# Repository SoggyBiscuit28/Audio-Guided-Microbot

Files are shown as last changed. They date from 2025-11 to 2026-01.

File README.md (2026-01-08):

Review Assignment Due Date (https://classroom.github.com/a/Ei5Ot7FV)

# Audio-Guided Microbot

### Team Biscuit

A voice-controlled microbot using ESP32-S3 with on-device machine learning for real-time audio command recognition.

---

## Overview

This project implements a microbot that responds to voice commands (Forward, Backward, Left, Right) using TensorFlow Lite Micro for on-device inference. The system includes BLE communication for manual override and a Python GUI for monitoring.

## Repository Structure

| Folder | Description |
|---|---|
| [`Code/`](./Code/) | ESP32-S3 firmware, GUI application, and ML model training notebooks |
| [`Demos/`](./Demos/) | Demo video and images |
| [`Presentation/`](./Presentation/) | Final evaluation presentation (PDF) |
| [`Report/`](./Report/) | Project report |

## Quick Links

- 📹 [Demo Video](https://drive.google.com/file/d/1aCh8zQsNOZ-Cvipodxt4e_dWg6QOUhP8/view?usp=drivesdk)
- 📁 [Code Documentation](./Code/README.md)

## Tech Stack

- **Hardware:** ESP32-S3, I2S MEMS Microphone, DRV8833 Motor Driver
- **Firmware:** PlatformIO, Arduino Framework, TensorFlow Lite Micro
- **GUI:** Python, PySide6, BLE Communication
- **ML:** TensorFlow/Keras, MFCC Feature Extraction

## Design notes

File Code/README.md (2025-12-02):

# Audio-Guided Microbot - Code Documentation

This folder contains all the source code for the Audio-Guided Microbot project. The system enables voice command control of a microbot using an ESP32-S3 with on-device machine learning for audio classification.

## Table of Contents

- [Overview](#overview)
- [Folder Structure](#folder-structure)
- [Components](#components)
  - [Firmware](#firmware)
  - [Communication Classification](#communication-classification)
  - [GUI](#gui)
  - [Model Training](#model-training)
- [Hardware Requirements](#hardware-requirements)
- [Getting Started](#getting-started)

---

## Overview

The Audio-Guided Microbot is an embedded system that:
- Captures audio input via I2S MEMS microphone
- Processes audio using on-device neural network inference (TensorFlow Lite Micro)
- Classifies voice commands (Forward, Backward, Left, Right)
- Controls motors based on recognized commands
- Communicates with a companion GUI via BLE for manual override and monitoring
- Includes obstacle detection using ultrasonic sensors

---

## Folder Structure

```
Code/
├── README.md                           # This file
├── Communication_Classification/       # ESP32 code for BLE and LoRa testing/classification
│   ├── BLE/
│   │   ├── Client.ino                  # BLE client for throughput testing
│   │   └── Server.ino                  # BLE server for throughput testing
│   └── LoRa/
│       ├── receiver.ino                # LoRa receiver with RSSI/SNR logging
│       └── Transmitter.ino             # LoRa transmitter for range testing
├── firmware/                           # Main ESP32-S3 firmware (PlatformIO project)
│   ├── platformio.ini                  # PlatformIO configuration
│   ├── src/
│   │   ├── main.cpp                    # Main application entry point
│   │   ├── config.h                    # Hardware pin configurations
│   │   ├── CommandDetector.cpp/.h      # Audio gating and command detection
│   │   ├── CommandProcessor.cpp/.h     # Command execution logic
│   │   ├── ble_commands.h              # BLE communication handlers
│   │   └── neopixel_motorpin.h         # Motor and NeoPixel pin definitions
│   └── lib/
│       ├── audio_input/                # I2S microphone sampling library
│       │   ├── I2SMicSampler.cpp/.h    # I2S MEMS microphone driver
│       │   ├── I2SSampler.cpp/.h       # Base sampler class
│       │   └── RingBuffer.h            # Circular buffer for audio samples
│       ├── audio_processor/            # Audio feature extraction
│       │   └── src/
│       │       ├── AudioProcessor.cpp/.h   # MFCC feature extraction
│       │       ├── HammingWindow.cpp/.h    # Hamming window function
│       │       └── kissfft/                # FFT library
│       ├── neural_network/             # TensorFlow Lite Micro inference
│       │   └── src/
│       │       ├── model.cc/.h         # Trained model weights
│       │       └── NeuralNetwork.cpp/.h    # Inference wrapper
│       └── tfmicro/                    # TensorFlow Lite Micro library
│           ├── tensorflow/             # TF Lite Micro core
│           └── third_party/            # Dependencies (flatbuffers, gemmlowp, ruy)
├── GUI/                                # Graphical User Interface
│   ├── ESP32/
│   │   └── Client.ino                  # ESP32 BLE client (connects laptop to microbot)
│   └── python_GUI/
│       ├── ble_gui.py           # PySide6 GUI for robot control and monitoring
│       └── requirements.txt            # Python dependencies for GUI
└── model/                              # Machine Learning model training
    ├── Generate Training Data Command Recognition.ipynb    # Data generation notebook
    ├── Train Model-All Words.ipynb                         # Model training notebook
    ├── Convert Trained Model To TFLite.ipynb               # TFLite conversion notebook
    └── requirements.txt                                    # Python dependencies
```

---

## Components

### Firmware

**Location:** `firmware/`

The main ESP32-S3 firmware that runs on the microbot. Built with PlatformIO using the Arduino framework.

**Key Features:**
- **Audio Input:** Captures audio via I2S MEMS microphone at 16kHz
- **Audio Gating:** Energy-based voice activity detection to filter noise
- **Neural Network Inference:** TensorFlow Lite Micro for on-device command recognition
- **Motor Control:** PWM-based motor control with joystick override support
- **BLE Communication:** Receives commands and sends status updates
- **Obstacle Detection:** Ultrasonic sensor integration for collision avoidance
- **Voltage Monitoring:** ADC-based battery voltage monitoring

**Supported Commands:**
| Code | Command | Action |
|---|---|---|
| 0 | Toggle Override | Enable/disable voice command mode |
| 1 | Forward | Move forward for 5 seconds |
| 2 | Backward | Move backward for 5 seconds |
| 3 | Left | Turn left for 5 seconds |
| 4 | Right | Turn right for 5 seconds |
| 6 | Controller Mode | Toggle joystick override mode |

**Pin Configuration (ESP32-S3):**
| Pin | Function |
|-----|---|
| GPIO18 | I2S Mic Serial Data |
| GPIO19 | I2S Mic Left/Right Clock |
| GPIO20 | I2S Mic Serial Clock |
| GPIO7 | ADC Voltage Sensor |
| GPIO4 | Ultrasonic Trigger |
| GPIO5 | Ultrasonic Echo |

---

### Communication Classification

**Location:** `Communication_Classification/`

Contains test code for evaluating BLE and LoRa communication protocols for the microbot.

#### BLE Testing
- **Server.ino:** Creates a BLE server that measures throughput by receiving data packets
- **Client.ino:** BLE client that sends test payloads and measures RSSI

#### LoRa Testing
- **Transmitter.ino:** Transmits packets at configurable intervals with SF12/BW125kHz
- **receiver.ino:** Receives packets and logs RSSI, SNR, and packet statistics

**LoRa Configuration:**
| Parameter | Value |
|---|---|
| Frequency | 433 MHz |
| Spreading Factor | 12 |
| Bandwidth | 125 kHz |
| Coding Rate | 4/5 |
| TX Power | 20 dBm |

---

### GUI

**Location:** `GUI/`

A Python-based graphical user interface for controlling and monitoring the microbot.

#### ESP32 Client (`ESP32/Client.ino`)
- Runs on a separate ESP32 connected to the laptop via USB
- Acts as a BLE bridge between the Python GUI and the ESP32-S3 microbot
- Forwards serial commands as BLE writes
- Receives BLE notifications and prints them to serial

#### Python GUI (`python_GUI/ble_gui.py`)
A modern PySide6 application with:

**Features:**
- Serial port selection with auto-baud detection
- Real-time communication console
- Robot movement controls (Forward, Backward, Left, Right)
- Keyboard arrow key shortcuts
- Xbox controller/joystick support for analog control
- Battery level monitoring with voltage display
- Current and voltage line graphs
- Speed indicator
- Obstacle detection status
- Motion state display
- Override mode toggles

**Requirements:**
```
PySide6
pyserial
pygame (optional, for joystick support)
```

---

### Model Training

**Location:** `model/`

Jupyter notebooks for training the voice command recognition model.

#### Notebooks:
1. **Generate Training Data Command Recognition.ipynb**
   - Generates synthetic training data for voice commands
   - Creates spectrograms and audio features

2. **Train Model-All Words.ipynb**
   - Trains a CNN model for command classification
   - Supports 4 command classes: Forward, Backward, Left, Right

3. **Convert Trained Model To TFLite.ipynb**
   - Converts the trained Keras model to TensorFlow Lite format
   - Quantizes the model for embedded deployment
   - Generates C header file for embedding in firmware

**Model Architecture:**
- Input: MFCC features from audio spectrograms
- Output: 4-class softmax (Forward, Backward, Left, Right)
- Optimized for ESP32-S3 with ~300KB tensor arena

---

## Hardware Requirements

- **ESP32-S3 DevKitC-1** (main microbot controller)
- **ESP32** (BLE bridge for laptop communication)
- **I2S MEMS Microphone** (e.g., INMP441)
- **DRV8833 Motor Driver** or similar H-bridge
- **DC Motors** (2x for differential drive)
- **HC-SR04 Ultrasonic Sensor**
- **LiPo Battery** with voltage divider for monitoring
- **NeoPixel LED** (optional, for status indication)

---

## Getting Started

### Firmware Setup

1. Install [PlatformIO](https://platformio.org/) in VS Code
2. Open the `firmware/` folder in PlatformIO
3. Connect ESP32-S3 via USB
4. Update `upload_port` and `monitor_port` in `platformio.ini` for your OS:
   ```ini
   ; Windows example
   upload_port = COM3
   monitor_port = COM3
   ```
5. Build and upload:
   ```bash
   pio run --target upload
   ```

### GUI Setup

1. Upload `GUI/ESP32/Client.ino` to a separate ESP32 using Arduino IDE
2. Install Python dependencies:
   ```bash
   pip install -r GUI/python_GUI/requirements.txt
   ```
3. Connect the ESP32 client to your laptop via USB
4. Run the GUI:
   ```bash
   python GUI/python_GUI/nble_gui.py
   ```

### Model Training

1. Install Jupyter and dependencies:
   ```bash
   pip install -r model/requirements.txt
   ```
2. Run notebooks in order:
   - Generate Training Data → Train Model → Convert to TFLite
3. Copy the generated model header to `firmware/lib/neural_network/src/model.cc`

---

## Communication Protocol

The GUI communicates with the microbot via BLE using simple text commands:

| Command | Description |
|---|---|
| `0` | Toggle voice command mode |
| `1` | Move forward |
| `2` | Move backward |
| `3` | Turn left |
| `4` | Turn right |
| `6` | Toggle joystick controller mode |
| `J x.xxx y.yyy` | Joystick vector (x, y in range -1.0 to 1.0) |

**BLE Service UUID:** `4fafc201-1fb5-459e-8fcc-c5c9c331914b`  
**BLE Characteristic UUID:** `beb5483e-36e1-4688-b7f5-ea07361b26a8`

---

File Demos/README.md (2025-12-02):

# Demo Videos

This folder contains demonstration videos of the Audio-Guided Microbot project.

## Project Demo

📹 **[Watch the Demo Video](https://drive.google.com/file/d/1aCh8zQsNOZ-Cvipodxt4e_dWg6QOUhP8/view?usp=drivesdk)**

The demo showcases:
- Voice command recognition (Forward, Backward, Left, Right)
- Real-time motor control based on audio classification
- BLE communication with the companion GUI
- Obstacle detection and avoidance
- Manual override using the Python GUI

---

## Features Demonstrated

| Feature | Description |
|---|---|
| Voice Commands | ESP32-S3 recognizes spoken commands using on-device ML |
| Motor Control | Differential drive responds to classified commands |
| BLE Communication | Real-time status updates and manual control |
| Obstacle Detection | Ultrasonic sensor prevents collisions |
| GUI Control | Python application for monitoring and override |
---

### Link
https://drive.google.com/file/d/1aCh8zQsNOZ-Cvipodxt4e_dWg6QOUhP8/view?usp=drivesdk

---

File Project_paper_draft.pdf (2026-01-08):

# Energy-Efficient Keyword Spotting for Autonomous Microbots using Gated CNN on Edge

Ayush
Dept. of Computer Science Engineering IIIT Hyderabad
Hyderabad, India

Pranav
Dept. of Computer Science Engineering IIIT Hyderabad
Hyderabad, India

Yashav
Dept. of Computer Science Engineering IIIT Hyderabad
Hyderabad, India

Raza
Dept. of Computer Science Engineering IIIT Hyderabad
Hyderabad, India

Abstract—Voice-controlled micro-robots typically rely on cloud-based processing, which introduces latency and privacy concerns. Edge-based solutions are constrained by limited battery life and computational resources. This letter presents an energy-efficient Keyword Spotting (KWS) system implemented on an ESP32-S3 microcontroller for a differential drive microbot. We propose a multi-stage gating mechanism combining Signal-to-Noise Ratio (SNR), Root Mean Square (RMS) energy, and Zero-Crossing Rate (ZCR) to filter non-speech audio before invoking a lightweight Convolutional Neural Network (CNN). The system achieves a command recognition latency of approximately 102 ms and extends battery life by preventing unnecessary model inference. Experimental results demonstrate robust offline control with high accuracy for four directional commands.
Index Terms—Keyword Spotting, Edge AI, Embedded Systems, Micro-robotics, Convolutional Neural Networks.
I. INTRODUCTION

Voice User Interfaces (VUI) have become a dominant modality for human-machine interaction, driven by the ubiquity of smart speakers and virtual assistants. At the core of these systems lies Keyword Spotting (KWS), a classification task designed to detect a predefined set of words or phrases within a continuous stream of audio. Unlike Large Vocabulary Continuous Speech Recognition (LVCSR) which transcribes full sentences, KWS focuses on identifying specific triggers, making it the critical first step in command-and-control applications.
Deploying robust KWS on the “edge”—specifically on microcontrollers (MCUs)—presents a distinct set of challenges compared to server-grade implementations. Edge devices, such as the ESP32-S3 used in this work, operate under severe resource constraints. They typically possess limited Static RAM (SRAM) for storing intermediate tensors and Flash memory for model weights. Furthermore, they lack the powerful GPUs found in cloud servers, relying instead on low-power CPUs or specialized vector instructions. Achieving high accuracy with low latency while fitting the model into these constraints requires careful architectural design and optimization, such as quantization.

A critical bottleneck in battery-operated edge KWS is energy consumption. Deep learning models, particularly Convolutional Neural Networks (CNNs), involve millions of multiply-accumulate (MAC) operations per inference. In a typical environment, a robot spends the vast majority of its time in silence or background noise. An “always-on” system that runs a full CNN inference on every audio frame is inherently inefficient, draining the battery rapidly even when no commands are spoken.

To address this, Our edge KWS system leverages a “gating” mechanism or Voice Activity Detection (VAD) stage. This technique introduces a hierarchical processing pipeline. A lowcomplexity, low-power algorithm continuously monitors the audio signal for speech-like characteristics. Only when this gate detects potential speech does it wake the downstream neural network to perform the expensive classification. This cascaded approach offers dual benefits: it drastically reduces the average power consumption by keeping the MCU in a lower-power state during silence, and it reduces false positives by filtering out non-speech acoustic events before they reach the classifier.

In this letter, we present a complete hardware and software implementation of an offline, voice-controlled microbot. We focus on optimizing the trade-off between recognition accuracy and energy consumption through a robust gating strategy and a quantized neural network.

This work makes the following contributions:

1) A lightweight CNN architecture optimized for the ESP32-S3 to recognize four navigational commands (Forward, Backward, Left, Right).
2) A robust multi-metric gating algorithm using Signal-to-Noise Ratio (SNR), Root Mean Square (RMS) energy, and Zero-Crossing Rate (ZCR) to filter noise and silence, significantly reducing computational load.
3) A complete offline implementation demonstrating real-time control with <120 ms latency and safety features.

II. SYSTEM ARCHITECTURE

The system is built around the Espressif ESP32-S3 SoC, which features a dual-core Xtensa LX7 processor with vector instructions (AI acceleration) and BLE 5.0.

A. Hardware Setup

The robot employs a differential drive configuration with N20 motors and a DRV8833 driver. Audio is captured via an INMP441 MEMS microphone using the I2S interface. An HC-SR04 ultrasonic sensor provides obstacle avoidance safety. Power is supplied by 4xAA batteries, necessitating strict energy management.

B. Software Pipeline

The processing pipeline consists of five stages:

1) Audio Acquisition: Continuous buffering of 16kHz audio samples.
2) Gating (VAD): Fast rejection of non-speech frames.
3) Feature Extraction: Conversion of raw audio to spectrograms.
4) Inference: 8-bit quantized CNN execution.
5) Post-Processing: Confidence thresholding and command execution.

III. PROPOSED METHOD

A. Multi-Stage Gating Mechanism

To minimize power consumption, we implement a “Speech Gate” that analyzes the raw audio buffer before feature extraction. The gate computes three metrics on the raw PCM data: Root Mean Square (RMS) energy, Zero-Crossing Rate (ZCR), and Signal-to-Noise Ratio (SNR).
The system maintains a running estimate of the background noise level (Nest) and noise ZCR (Zest), updated during non-speech frames using a first-order low-pass filter with an adaptive coefficient α:

Nest[t] = (1 − α) · Nest[t − 1] + α · AvgAbs[t] (1)

where α is set to 0.05 for noise-like frames and 0.005 otherwise, ensuring the noise floor adapts quickly to environmental changes but remains stable during speech.
The gate transitions to an “open” state only if a set of strict conditions are met for kmin = 2 consecutive frames:

(SNR > TSNR ∨ RMS > TRMS) ∧ (ZCR < TZCR) (2)

where TSNR = 1.25, TRMS = 58.5, and TZCR = 0.28. A secondary “Strong” threshold set (TSNR High = 2.15, TRMS High = 106.5) allows for faster triggering on clear, loud commands. Once triggered, the gate remains open for a “hangover” period of 4 frames to capture the tail of the utterance.

B. Feature Extraction
Upon gate activation, the system processes a 1-second audio buffer (L = 16000 samples). We compute a spectrogram using a sliding Hamming window of size W = 320 (20 ms) with a step size of S = 160 (10 ms). For each window, a 512-point Fast Fourier Transform (FFT) is computed.
To reduce dimensionality, the magnitude squared of the FFT bins is pooled using average pooling with a kernel size of 6. The result is log-transformed to compress the dynamic range:

S[t, f] = log10

1
P

P

X⁻¹

i=0

|X[t, f · P + i]|

2 + ϵ

!
(3)

This yields a compact input tensor of shape (99, 43, 1), representing time, frequency, and channels respectively.

C. Lightweight CNN Architecture
We designed a compact CNN to fit within the ESP32-S3’s 384KB SRAM. The model takes a 99 × 43 × 1 spectrogram input and processes it through the following layers:
1) Conv2D: 4 filters, 3 × 3 kernel, ReLU activation, L2 regularization (0.001).
2) MaxPool2D: 2 × 2 pooling.
3) Conv2D: 4 filters, 3 × 3 kernel, ReLU activation, L2 regularization (0.001).
4) MaxPool2D: 2 × 2 pooling.
5) Flatten followed by Dropout (0.1).
6) Dense: 80 units, ReLU activation, L2 regularization (0.001), Dropout (0.1).
7) Output Dense: 5 units (Forward, Backward, Left, Right, Unknown), Softmax activation.
The model contains a total of 77,473 parameters. It is trained using the Adam optimizer and Categorical Cross-Entropy loss. Post-training, the model is converted to TensorFlow Lite for Microcontrollers (TFLite Micro) with full integer quantization (int8). This reduces the model size to approximately 81 kB, allowing it to reside entirely in the MCU’s internal flash and execute efficiently in RAM.
D. Post-Processing & Safety
Raw model probabilities are filtered to prevent false positives. A command Ci

is accepted only if its probability P(Ci) exceeds a class-specific threshold Ti (e.g., Tfwd = 0.70, Tlef t = 0.50) and the margin against the second-best class exceeds M = 0.15.

P(Ci) > Ti | ∧ | (P(Ci) − max j̸=i
P(Cj )) > M | (4)

A cooldown period of 1000 ms is enforced after a successful detection to prevent repeated triggering from echoes.

IV. EXPERIMENTAL RESULTS

A. Model Evaluation
The model was trained on a custom dataset of the four target commands plus a set of “unknown” words and background noise. The training process achieved a validation accuracy of 92.87%.

The confusion matrix (Table I) illustrates the model’s performance across all classes. The high diagonal values indicate robust classification, with minimal confusion between directional commands.

TABLE I
CONFUSION MATRIX (NORMALIZED)
True/Pred | Fwd | Back | Left | Right | Unk
Fwd | 0.94 | 0.01 | 0.02 | 0.01 | 0.02
Back | 0.01 | 0.93 | 0.01 | 0.02 | 0.03
Left | 0.02 | 0.01 | 0.91 | 0.01 | 0.05
Right | 0.01 | 0.02 | 0.01 | 0.92 | 0.04
Unk | 0.03 | 0.02 | 0.03 | 0.02 | 0.90
B. Latency and Performance
The end-to-end latency from the end of a spoken command to motor actuation was measured at approximately 102 ms. This falls well within the target of <120 ms for perceived real-time response.
C. Gating Efficiency
The gating mechanism successfully filters out background noise and silence. In a quiet environment, the gate remains closed >90% of the time, preventing the CPU from running the computationally intensive FFT and CNN inference. This significantly reduces the average current consumption.
D. Battery Life
On 4xAA batteries (approx. 2500mAh capacity), the robot achieves a runtime of:
- Idle (Listening): ∼3.5 hours
- Active (Moving): ∼2.25 hours (at 100% motor duty cycle)
E. Resource Usage
- Model Size: ∼81 kB
- Tensor Arena: 50 kB
- Inference Time: <100 ms
V. CONCLUSION
We presented a fully offline, voice-controlled microbot system. By combining a low-cost gating stage with a quantized CNN, we achieved robust command recognition on a resourceconstrained ESP32-S3. The system balances latency, accuracy, and power efficiency, making it suitable for low-power edge robotics applications. Future work will explore on-device learning to adapt to specific user voices.

REFERENCES

[1] Y. Zhang et al., “Hello Edge: Keyword Spotting on Microcontrollers,” arXiv preprint arXiv:1711.07128, 2017.
[2] P. Warden, “Speech Commands: A Dataset for Limited-Vocabulary Speech Recognition,” arXiv preprint arXiv:1804.03209, 2018.

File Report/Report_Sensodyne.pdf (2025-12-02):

# Audio Guided Microbot

### Documentation (Embedded Systems Workshop)

### Team Sensodyne (#17) — Ayush, Pranav, Yashav, Raza Under Prof. Abhishek Srivastava TA: Inesh Dheer

### December 2, 2025

### At a Glance (Our Project)

An autonomous microbot that listens for four simple voice commands (forward, back, left, right), moves safely, and can be taken over from a laptop with a joystick. All recognition happens on the bot (no internet). Bluetooth (BLE) is our main, encrypted link. LoRa is optional for long range. The bot stops if an obstacle is too close or if the link drops.

- Why this is useful: hands-free control, works offline and keeps audio private, easy supervision with a GUI.
- Core pieces: the mic (ears), a tiny on-device model (brain), motor driver + wheels (legs), ultrasonic sensor (safety), BLE (link), and a simple desktop GUI (eyes).

### Contents

1 Problem & Our Approach | 3
2 How the System Fits Together | 5
3 The Parts We Used (and why) | 5
4 The Brain: How We Understand the Voice | 6
5 Communication & Security (practical view) | 8
6 What the GUI shows (operator view) | 8
7 What happens on each command (simple behavior) | 9

8 What We Calibrated & Tested | 9
9 Results (short and clear) | 10
10 Challenges & What We Changed | 10
11 How to Run (In short) | 10
12 Implementation Details (how our code works, in simple words) | 10

### 1 Problem & Our Approach

### 1.1 Introduction

Small robots are great for demos, labs, and quick tasks—but most voice control systems depend on the cloud, which adds delay and privacy issues. Our goal was to make a tiny microbot that you can talk to in plain words (forward, back, left, right), that reacts quickly, stays safe around obstacles, and can be taken over instantly from a laptop—all while working fully offline.
The design favors:
- Simplicity for the operator: four clear voice commands, one clean GUI, and an instant Manual Override.
- Safety first: obstacle halts and link-loss stop; no surprises in crowded rooms.
- Privacy by default: on-device recognition—no audio leaves the bot.
- Practical hardware: ESP32-S3 with built-in BLE, a single digital mic, and a basic differential drive.

### 1.2 Problem Statement & Constraints

We want a voice-driven microbot that is fast, safe, and private, using inexpensive parts. It should understand four commands, move appropriately, and be supervise-able from a laptop. No cloud is allowed.

Functional requirements
- Recognize forward, back, left, right on-device and act on them.
- Halt forward motion automatically when an obstacle is detected at 6 cm.
- Provide a Manual Override via GUI to drive with joystick/keys at any time.
- Keep the operator informed with simple BLE messages: FORWARD, LEFT, OBSTACLE, IDLE, etc.
- Stop safely if the operator link is lost (short timeout, ∼400 ms).

Non-functional requirements
- Offline: no internet; audio never leaves the device.
- Low latency: decision in well under 150 ms (we achieve ∼102 ms).
- Small model: must fit in microcontroller memory (we use ∼81 kB).
- Low false triggers: practical guards for noisy rooms (energy/ZCR gate, short memory, per-command confidence, cooldown).
- Battery-friendly: run on 4×AA cells for a couple of hours (measured 2.25 3.5 h depending on duty).

Scope & assumptions (hardware/environment)
- Compute: ESP32-S3; on-board BLE; FreeRTOS tasks.
- Audio: single INMP441 digital mic; 16 kHz sampling; ∼1 s analysis window.
- Drive: DRV8833 + 2×N20 motors (differential); ultrasonic sensor (HC-SR04) facing forward.
- Typical spaces: classrooms, labs, corridors; normal indoor noise.
- Comms: BLE (primary, encrypted when paired); LoRa optional with app-level encryption when used.

### 1.3 Objectives & Success Criteria

- Command responsiveness: voice→action in ≤120 ms (met: ∼102 ms).
- Safety halt: forward motion stops at <6 cm and on link loss (met: periodic checks + timeout stop).
- Operator clarity: GUI mirrors state with simple words; Manual Override is instant.
- Robustness in noise: few/no unintended moves in typical indoor noise thanks to gating + thresholds + cooldown.
- Runtime on 4×AA: 2.25 −3.5 h depending on duty (measured, see §8.3).

### 1.4 Our Solution (high level)

- Listen & understand: a compact model on the ESP32-S3 recognizes forward/ back/left/right.
- Move safely: before and during forward motion, we check distance in front; halt at 6 cm.
- Stay connected: BLE is primary (encrypted by default when paired); optional LoRa adds range with an extra app-level lock (encryption) on messages.
- Be easy to control: a desktop GUI shows status and lets the operator drive instantly with a joystick.

### 2 How the System Fits Together

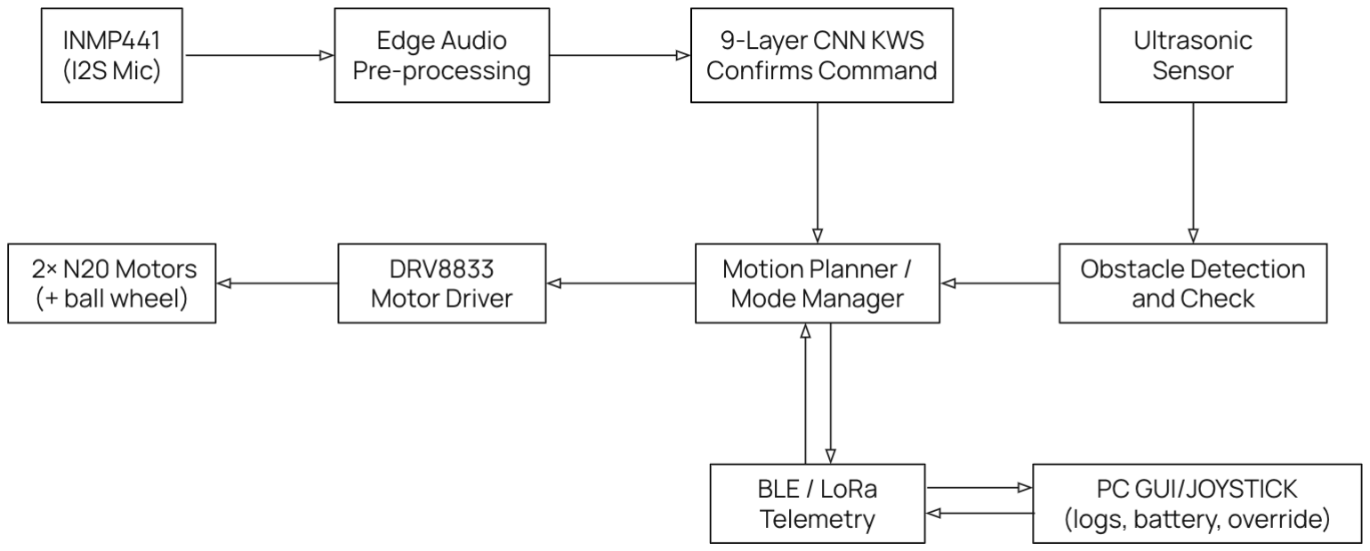
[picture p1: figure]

Figure 1: Mic (hear) → tiny model (decide) → safety check (stop if needed) → wheels (act). BLE links the bot to the GUI.

Simple flow Mic hears the word → we turn the sound into a small picture-like grid → the tiny model picks the best of four commands → a few “common-sense” checks avoid mistakes → motors run or stop → GUI shows what’s happening and can take over.

### 3 The Parts We Used (and why)

- ESP32-S3 board (brain): enough memory to run our tiny model on-device; built-in BLE keeps wiring simple.
- INMP441 microphone (ears): clean digital mic input.
- HC-SR04 ultrasonic (safety): halts forward motion within a set distance (default 6 cm).
- DRV8833 + 2×N20 motors (legs): sturdy differential drive; easy to control with four pins (IN1..IN4).
- Power: 4×AA cells with regulation; we measured runtime at different speeds (see §8.3).
- Shell & PCB: small 3D-printed cover and a simple PCB to avoid loose wires and reduce noise.

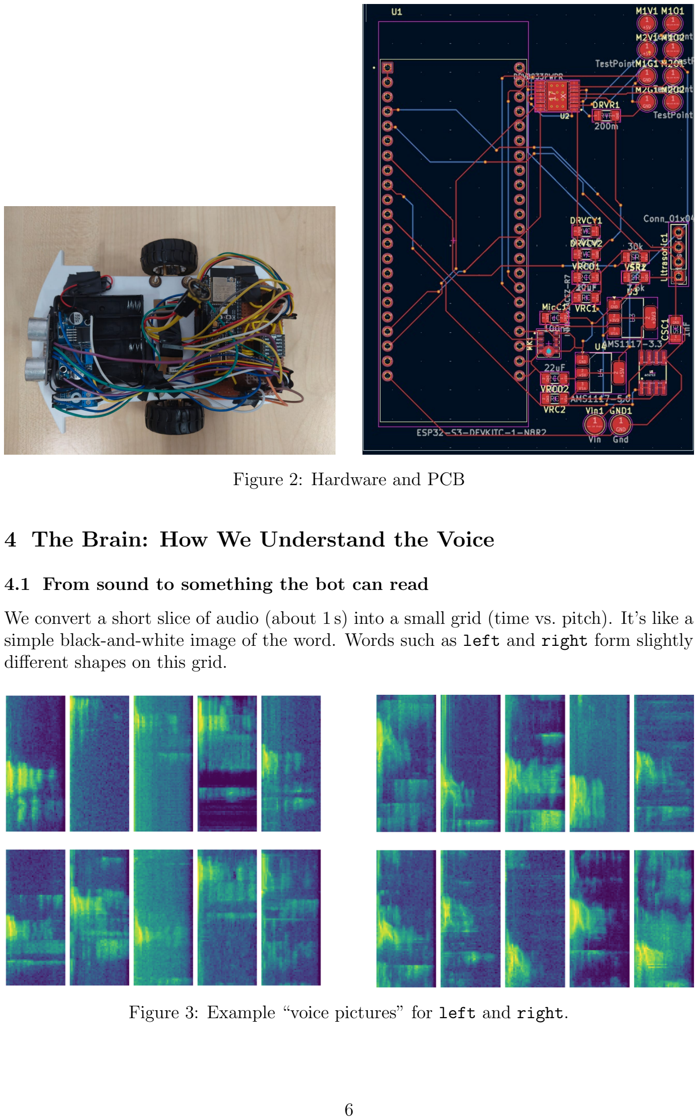
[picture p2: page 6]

Figure 2: Hardware and PCB

### 4 The Brain: How We Understand the Voice

### 4.1 From sound to something the bot can read

We convert a short slice of audio (about 1 s) into a small grid (time vs. pitch). It’s like a simple black-and-white image of the word. Words such as left and right form slightly different shapes on this grid.

Figure 3: Example “voice pictures” for left and right.

### 4.2 What the tiny model does

- A very small CNN looks for patterns in those grids.
- Size on device: ∼81 kB; decision time: ∼102 ms.
- Why this matters: quick reactions, fits in memory, fully offline (no privacy worries).

### 4.3 How we avoid mistakes in noisy rooms (practical guards)

We layer a few friendly checks around the model so the bot doesn’t move because of coughs or background talk.
1. Only listen when speech is present (a simple gate): we look at loudness, steadiness, and how often the signal crosses zero. If it looks like real speech, we “open the gate” and run the model; otherwise we skip it and treat it as silence.
2. Confidence per word: each command has its own “confidence to accept” and a “margin” over the second best. Clear words pass easily; unclear ones are ignored.
3. Short memory: we keep a tiny rolling window of the last few model outputs and accept only if the same command stays on top—this avoids one-frame spikes.
4. Cooldown: after acting on a word, we wait a bit before accepting the same word again—helps with echoes.

Quick reference (from firmware)

All of this is already coded; here are the friendly names and values your teammates will tweak most often.

Table 1: Speech gate (when to even run the model)

What it checks | Current setting

Needs to be louder than recent background (SNR) normal 1.25, “strong” 2.15
Minimum steady loudness (RMS) | normal 58.5, “strong” 106.5
Extra margin above average noise (abs delta) | 6.5
How busy the signal is (zero-crossing rate) | must be ≤ noise+margin; cap 0.28 (+0.08 margin)
Open gate after this many “hits” | 2 (keep open briefly for up to 600 ms)

Table 2: Accepting a command (per-word confidence)

Command | Min confidence Extra margin over 2nd
forward | 0.70 | 0.35
backward | 0.71 | 0.37
left | 0.50 | 0.18
right | 0.48 | 0.15
(unknown/silence) 0.50 | 0.20

Extra: when speech is very strong, the code can relax these slightly (to 0.45/0.15) so good words trigger faster. Cooldown between accepted commands: 1,000 ms. Debug status prints every 200 ms.

### 5 Communication & Security (practical view)

### 5.1 Bluetooth Low Energy (BLE) — our main link

BLE is the default. It’s quick, stable indoors, and already encrypted once paired (we use normal paired operation). We send short text updates like FORWARD, LEFT, OBSTACLE, IDLE so the GUI mirrors the bot’s state. If packets stop for a short time, the bot stops.

### 5.2 LoRa — optional long-range

When we need distance, we can switch to LoRa. Because LoRa itself isn’t end-to-end encrypted, we add a simple lock on the message (shared secret → encrypted payload) so packets stay private and tamper-evident.

### 6 What the GUI shows (operator view)

- One window to connect, see logs, battery and motion state.
- Manual Override button: instantly take control with keys or a joystick; the bot switches out of voice mode.
- Safety: if BLE packets stop arriving for a short time (∼400 ms), the bot auto-stops.

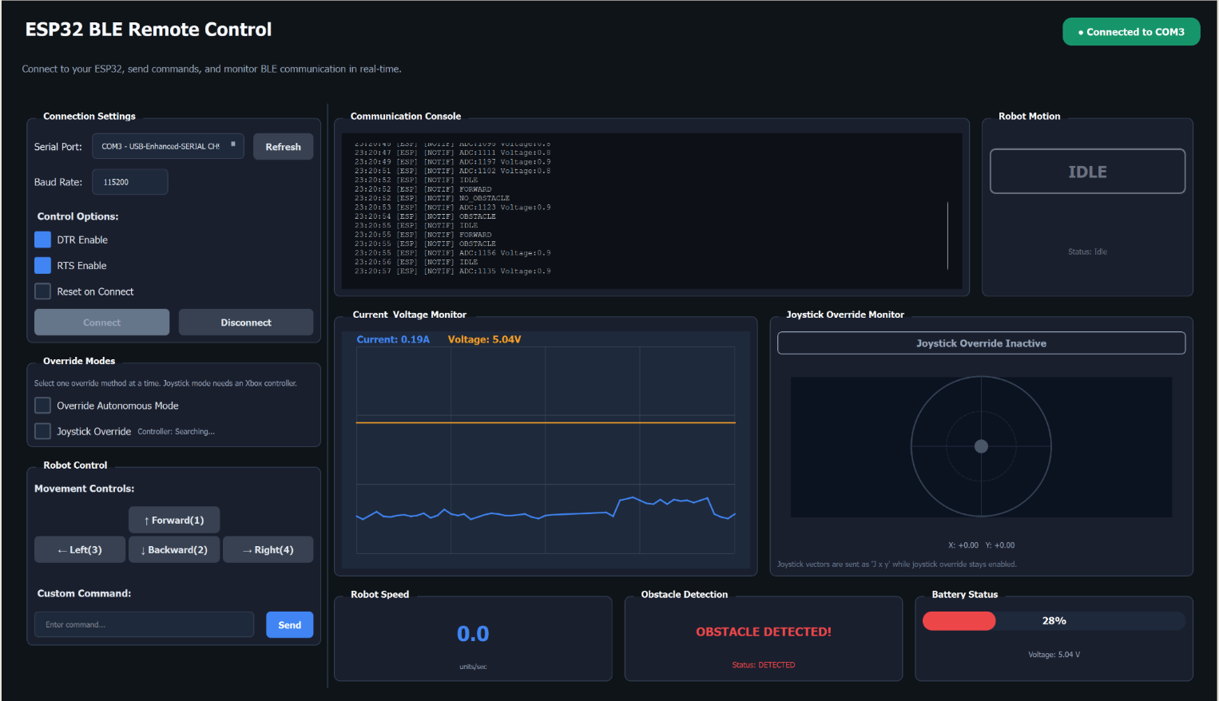
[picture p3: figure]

Figure 4: Remote GUI: status, logs, and joystick drive.

### 7 What happens on each command (simple behavior)

Below is how the bot moves after a command is accepted. We also send a short BLE message for the GUI.

Table 3: Command behavior (summarized from firmware)

Command Safety check | Motion pins (IN1..IN4) | Typical duration
forward | Check distance each step; stop < 6 cm 1:HIGH,2:LOW,3:LOW,4:HIGH | up to ∼9 s (rechecks every 200 ms)
backward | No front check needed | 1:LOW,2:HIGH,3:HIGH,4:LOW | ∼5 s
left | No front check needed | 1:HIGH,2:LOW,3:HIGH,4:LOW | ∼5 s (pivot)
right | No front check needed | 1:LOW,2:HIGH,3:LOW,4:HIGH | ∼5 s (pivot)

At the end of any move, we set all four pins LOW, send IDLE, and disable the motor
driver to save power.

Front distance sensor (forward only) We trigger the ultrasonic sensor, read the echo, and compute distance. If it’s valid and < 6 cm, we stop immediately; otherwise we continue but recheck frequently.

### 8 What We Calibrated & Tested

### 8.1 Audio & model

- Trim clips to keep speech; keep lengths consistent so the “voice picture” is stable.
- Tune confidence thresholds (per word) and cooldown until the bot feels both responsive and safe.
- In busy spaces, the speech gate + “short memory” window keep false triggers rare.

### 8.2 Motion & safety

- Map joystick values to left/right wheel speeds; add a small left/right correction so “straight” is truly straight.
- Verify the 6 cm stop distance with a ruler and adjust only if needed.

### 8.3 Battery life (4×AA (600mah each)

Table 4: Runtime vs. movement (measured)

Motor duty Avg current (A) Runtime (h) hh:mm

0% | 0.18 | ∼3.50 | ∼3:30
25% | 0.198 | ∼3.00 | ∼3:00
50% | 0.215 | ∼2.75 | ∼2:45
75% | 0.232 | ∼2.50 | ∼2:30
100% | 0.250 | ∼2.25 | ∼2:15

### 8.4 BLE and LoRa (field notes)

Indoors, BLE is strong across rooms and a couple of walls; very long hallways or lots of motion can weaken it. LoRa reaches far in open sight; when we use it, we keep our app-level lock (encryption) on messages.

### 9 Results (short and clear)

- On-device voice: ∼102 ms decision time; smooth in quiet rooms; usable in busy rooms thanks to the guards.
- Safety working: stops within 6 cm and also on link loss.
- Operator experience: joystick feels immediate; GUI is clear; manual override is instant.

### 10 Challenges & What We Changed

- Early plan used multiple mics to find direction—hardware wasn’t precise enough, so we pivoted to solid keyword control.
- A browser model worked online but not on the board; switching to a direct .tflite with a tiny runtime fixed it.
- Noise from wiring/breadboards caused false triggers; a PCB and the extra guards stabilized behavior.

### 11 How to Run (In short)

1. Flash the ESP32-S3 with the firmware that includes the tiny model file (.tflite).
2. Power the bot; pair over BLE from the GUI.
3. Choose Voice mode to use keywords, or tap Manual Override for joystick/keys.
4. Keep obstacles ≥ 6 cm in front when moving forward; if the link drops, the bot will stop on its own.

### 12 Implementation Details (how our code works, in simple words)

This section explains what actually runs on the board and how each piece talks to the next. We keep it practical and match the names you will see in code and logs.

### 12.1 Voice path: from mic to a decision

1. Keep the last ∼1 second of audio in memory We continuously sample the mic and store it in a ring buffer (AUDIO LENGTH=16000 samples). Why: when a word is spoken, we already have the recent audio to analyze.

2. Decide if this even sounds like speech (“open the gate”) Before running the tiny model, we check simple metrics over the last second: average loudness, steadiness (RMS), and how often the signal crosses zero (ZCR). If it looks like real speech (loud enough, steady enough, and not too “buzzy”), we open the gate; otherwise we skip this turn. Names in code: shouldRunInference(...) with thresholds like SNR 1.25 / 2.15, RMS 58.5 / 106.5, max ZCR 0.28 (+0.08 margin), min hits 2, release 600 ms. Why: saves time and avoids reacting to
coughs and background chatter.
3. Turn audio into a small “voice picture” With the gate open, we build a compact spectrogram (a time–pitch grid). Name in code: AudioProcessor::get spectrogram(...).
4. Run the tiny model on that picture The model returns 5 scores: forward,
backward, left, right, (unknown/silence). Name in code: m nn->predict();
m nn->getOutputBuffer().
5. Keep a short memory of recent outputs We store each new set of scores in a rolling window (COMMAND WINDOW rows). Internally we keep them as log values so combining them stays numerically stable. Name in code: cachePredictionRow(...) updates m scores[window][class].
6. Pick the best command, check confidence and margin We add up the windowed scores per class, compute a best class and a runner-up, then require: (a) Min confidence for that command, and (b) extra margin over the second place. Per-command thresholds in code:
- forward → 0.70 (min), 0.35 (margin)
- backward → 0.71, 0.37
- left → 0.50, 0.18
- right → 0.48, 0.15
- unknown/silence → 0.50, 0.20

When the speech looks very strong, the code can relax the generic thresholds slightly
(to ∼0.45/0.15) so good words trigger faster. Name in code: see kCommandProbabilityThresholds, kCommandProbabilityMargins and the accept command checks.
7. Cooldown so echoes don’t double-trigger After we act on a word, we wait 1000
ms before we accept the same word again. Name in code: kDetectionCooldownMs
= 1000.

Debugging while you test Every ∼200 ms we print a compact line showing gate status (loudness, ZCR, SNR), top command, probabilities, thresholds, and whether we accepted it. Name in code: kDebugLogIntervalMs = 200. This is the first place to look if the bot is too jumpy or too sleepy.

### 12.2 Command path: from a decision to motor motion

Once a command is accepted, we don’t move motors directly from the detector thread. Instead, we queue the command, and a separate task performs the action. Why: keeps the audio/model loop smooth and responsive.

1. Queue the command queueCommand(index, best score) pushes into a FreeR-TOS queue (xQueueSendToBack).
2. A dedicated task executes it commandQueueProcessorTask(...) waits on the queue and calls processCommand(index).
3. What each command does (summarized)
- forward Before moving, we ping the ultrasonic sensor and compute distance. If it’s valid and < 6 cm, we report OBSTACLE and do not move. Otherwise we enable the driver (DRV EEP = HIGH), set motor pins to forward (IN1=HIGH, IN2=LOW, IN3=LOW, IN4=HIGH) and keep rechecking distance roughly every 200 ms in a short loop. If at any step an obstacle comes within 6 cm, we stop immediately and report OBSTACLE.
- backward Enable driver and set reverse pins (IN1=LOW, IN2=HIGH, IN3=HIGH, IN4=LOW) for a brief, fixed duration.
- left/right Pivot in place by driving wheels in opposite directions. Left: (IN1=HIGH, IN2=LOW, IN3=HIGH, IN4=LOW). Right: (IN1=LOW, IN2=HIGH, IN3=LOW, IN4=HIGH).
4. Always finish safely After any command completes (or is interrupted by an obstacle), we: set IN1..IN4 = LOW, send IDLE over BLE, and disable the motor driver (DRV EEP = LOW) to save power.

BLE messages you’ll see in the GUI On each action we notify short, humanreadable strings: FORWARD, BACKWARD, LEFT, RIGHT, OBSTACLE, NO OBSTACLE, IDLE. These make it obvious what the bot is doing and why it stopped.

### 12.3 Safety logic (forward motion + link loss)

- Obstacle stop (forward only) The distance check runs before moving and during the forward run (periodic pings). If distance < 6 cm at any instant, we stop and show OBSTACLE.
- If the operator link drops The GUI sends frequent small updates. If those stop for a short window (∼400 ms), the bot falls back to IDLE/stop. Tip: if you’re testing without the GUI, keep voice mode enabled so the safety still holds.

### 12.4 Where to tune (friendly knobs)

- How eager the bot is to treat audio as speech: SNR/RMS/ZCR thresholds (“gate”). If it’s too jumpy, raise SNR/RMS or tighten ZCR. If it’s too sleepy, lower them slightly.
- How strict a word must be: per-command confidence and margin. If “right” is mis-heard, raise its threshold or margin a little.
- Repeat protection: cooldown (1000 ms). Increase for echoey rooms; decrease if you want rapid repeated turns.

### 12.5 What runs in parallel (timing picture)

- The detector loop samples audio, opens/closes the speech gate, builds the voice picture, runs the model, and decides on commands. It keeps the UI responsive by not touching motors directly.
- The command task takes accepted commands from the queue and handles motors + safety checks.
- The BLE/GUI loop shows state and allows instant Manual Override (it simply bypasses voice and drives the same motor pins).

### 12.6 If something feels off (quick troubleshooting)

- Bot triggers on noise: raise SNR/RMS gate; raise per-command confidence; check wiring/PCB ground.
- Bot misses clear words: slightly lower per-command threshold; reduce margin; ensure the mic opening is unobstructed.
- Forward keeps stopping: confirm ultrasonic wiring; measure if your desk is within 6 cm; try temporarily raising the stop distance to test.
- GUI shows no updates: re-pair BLE; ensure notifications are enabled; watch serial logs for IDLE/OBSTACLE.

### Appendix A — Parameters (from firmware)

- Audio slice length: AUDIO LENGTH = 16000 samples (≈ 1 s at 16 kHz).
- Window & step: WINDOW SIZE = 320 (≈ 20 ms), STEP SIZE = 160 (≈ 10 ms hop).
- Pooling: POOLING SIZE = 6 (compact “voice picture”).
- Gate thresholds: SNR 1.25/2.15, RMS 58.5/106.5, max ZCR 0.28 (+0.08), min hits 2, hangover hits 4, release 600 ms.
- Per-word acceptance: see table in §The Brain.
- Cooldown: 1000 ms; Debug print interval: 200 ms.
- BLE messages: "FORWARD", "BACKWARD", "LEFT", "RIGHT", "OBSTACLE", "NO OBSTACLE", "IDLE".
- Ultrasonic pins (example in code): TRIG GPIO 4, ECHO GPIO 5 (adjust if
your wiring differs).

### Appendix B — Figures added from the build

- figures/block-diagram.png (single architecture diagram)
- figures/hardware.jpg (top view of the bot)
- figures/pcb.jpg (assembled PCB)

- figures/spectrogram-left.png, figures/spectrogram-right.png
- figures/gui.png (GUI screenshot)

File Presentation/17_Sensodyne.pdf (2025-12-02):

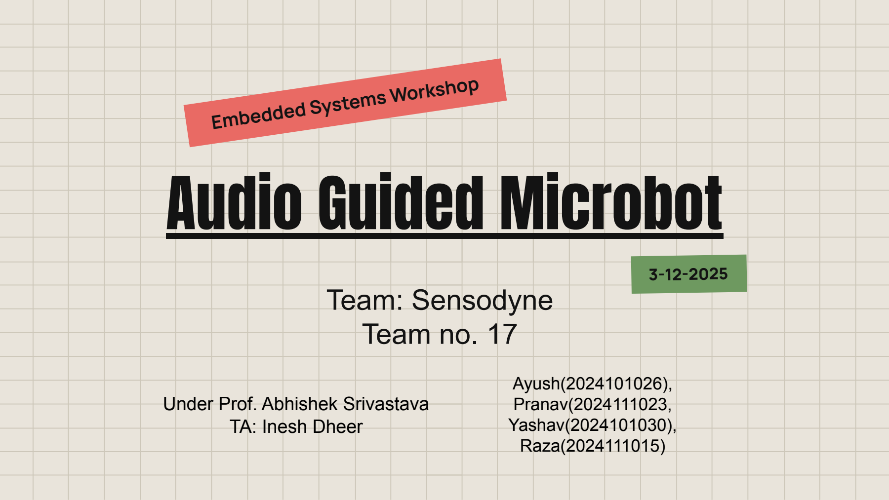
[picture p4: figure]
Audio Guided Microbot; Embedded Systems Workshop; Team: Sensodyne Team no. 17; Under Prof. Abhishek Srivastava TA: Inesh Dheer; Ayush(2024101026), Pranav(2024111023, Yashav(2024101030), Raza(2024111015)

# Problem Statement

The aim of this project is to design an intelligent
autonomous microbot system equipped with a MEMS microphone and will be capable of detecting and identifying commands (edge computing) in real time and take action against it.

The system will include secure wireless communication for remote operation, and a comprehensive GUI-based dashboard to monitor and control the microbot.

- Server & Dashboard:

Single GUI to monitor status and logs, switch modes, and allow instant operator takeover with clear state.

- Audio Classification:

On-device, real-time recognition of a small command set; robust to noise/speaker variation with low false triggers.

- Networking:

Heavy amounts of classification of dierent communication methods to choose the most reliable and secure option for communication link.

# Problem Statement

The aim of this project is to design an intelligent
autonomous microbot system equipped with a MEMS microphone and will be capable of detecting and identifying commands (edge computing) in real time and take action against it.

The system will include secure wireless communication for remote operation, and a comprehensive GUI-based dashboard to monitor and control the microbot.

- Movement:

Compact mobility with
precise maneuvers;
automatically halt
forward motion within a
defined obstacle range.

## - Reliable Voice-Command Guidance

## - Secure wireless communication (BLE / LoRa)

## - Low footprint (small, low‑power, low‑cost)

## - GUI to keep track of the bot (baery, logs, control)

## - Obstacle Detection and Avoidance

# Problem Statement

# (broken down)

## - Should have Manual Override

Voice makes operation
simple for quick tasks
and improves
accessibility.
Eg. Wheelchair
automation, household
transport

Works
oine &
private

Library
monitoring

Safety &
supervision | Spy Bot

POC for AI
computational
model on edge

# Motivation

Hands-free
Control

Edge KWS on ESP32‑S3
avoids cloud latency and
protects audio data.

Autonomous navigation
around a fixed path, and
generates a heatmap for
noise across the library

Obstacle stop + PC
telemetry/logs for
accountability in places
such as Factories.

Recognizes text around
a bugged spot, and
sends it wirelessly and
reliably over a large time period of time

Reproducible build for
labs, hackathons, and
student research.

# The “Sensodyne” Solution

# (High-Level)

The Concept: An autonomous microbot that uses Edge Computing. It thinks and acts locally.

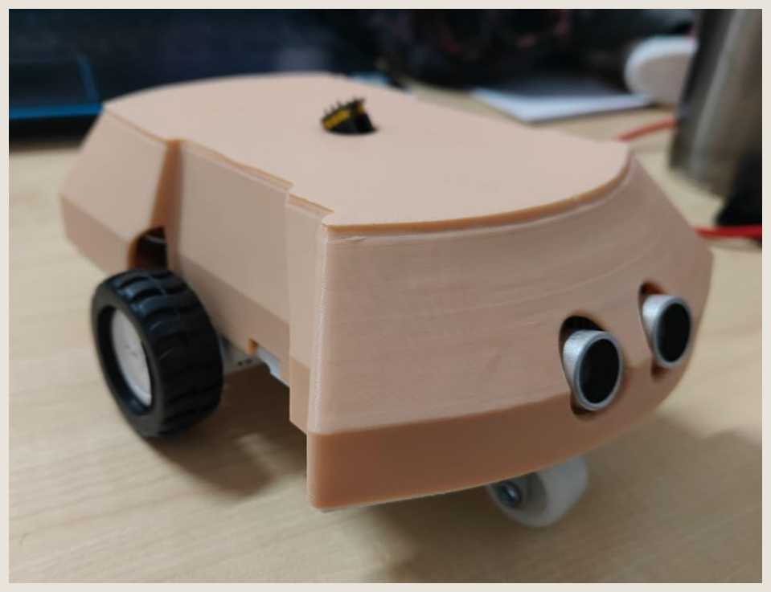
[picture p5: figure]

Core Capabilities:

- Real-time Keyword Spotting (KWS).
- Obstacle Avoidance (Safety).
- Secure Wireless Telemetry (BLE/LoRa)

Use Cases: Wheelchair automation, industrial monitoring in privacy-sensitive areas, or "Spy Bots".

# The Breakdown

# Spectrogram Parameters

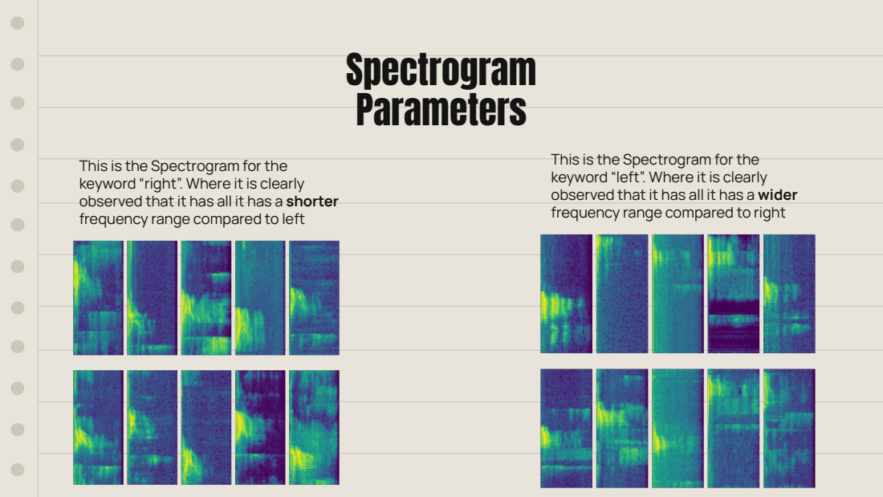
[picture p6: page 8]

This is the Spectrogram for the
keyword “left”. Where it is clearly
observed that it has all it has a wider
frequency range compared to right

keyword “right”. Where it is clearly
observed that it has all it has a shorter
frequency range compared to left

# Edge AI:

# KWS using CNN

## CNN model: 9 layers, ~77.5k parameters

## 5 layers dedicated to robust audio pre‑processing

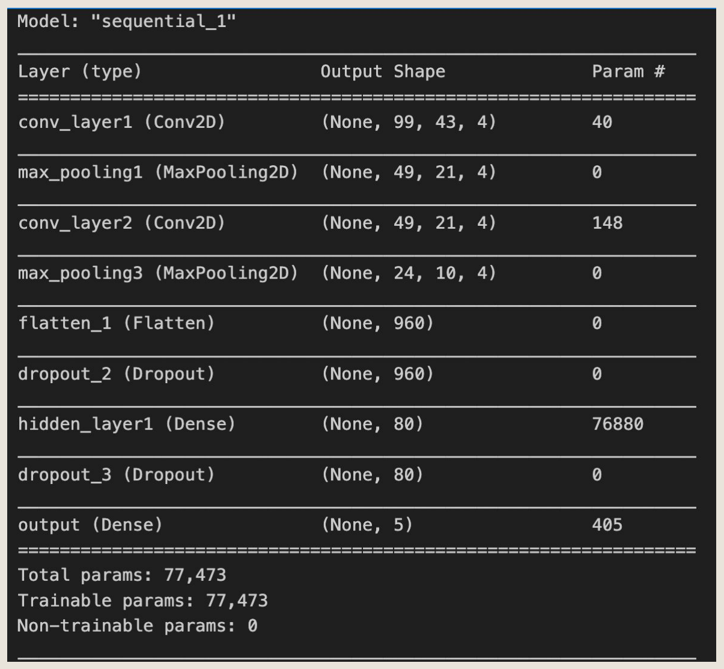
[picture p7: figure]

## Commands: forward, back, left, right

## Runtime: Fully on‑board (no internet) → low latency, consistent behavior

## On‑device smoothing: confidence

## threshold + debounce to reduce false triggers

## Size

## Spectrogram Processing

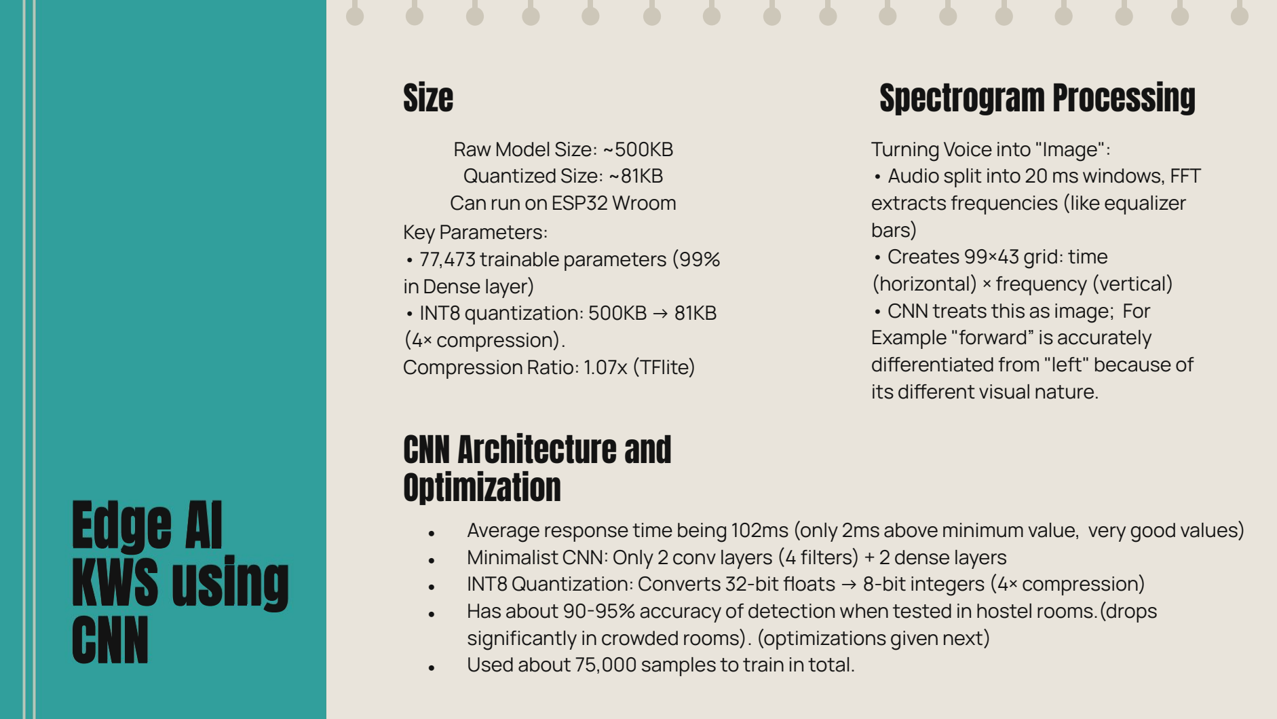
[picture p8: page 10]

Raw Model Size: ~500KB
Quantized Size: ~81KB
Can run on ESP32 Wroom
Key Parameters:
- 77,473 trainable parameters (99% in Dense layer)
- INT8 quantization: 500KB → 81KB (4× compression).
Compression Ratio: 1.07x (TFlite)

# Edge AI KWS using CNN

## CNN Architecture and Optimization

Turning Voice into "Image":
- Audio split into 20 ms windows, FFT extracts frequencies (like equalizer bars)
- Creates 99×43 grid: time (horizontal) × frequency (vertical)
- CNN treats this as image; For Example "forward” is accurately dierentiated from "left" because of its dierent visual nature.
- Average response time being 102ms (only 2ms above minimum value, very good values)
- Minimalist CNN: Only 2 conv layers (4 filters) + 2 dense layers
- INT8 Quantization: Converts 32-bit floats → 8-bit integers (4× compression)
- Has about 90-95% accuracy of detection when tested in hostel rooms.(drops significantly in crowded rooms). (optimizations given next)
- Used about 75,000 samples to train in total.

# Confusion Matrix (Latest Dataset)

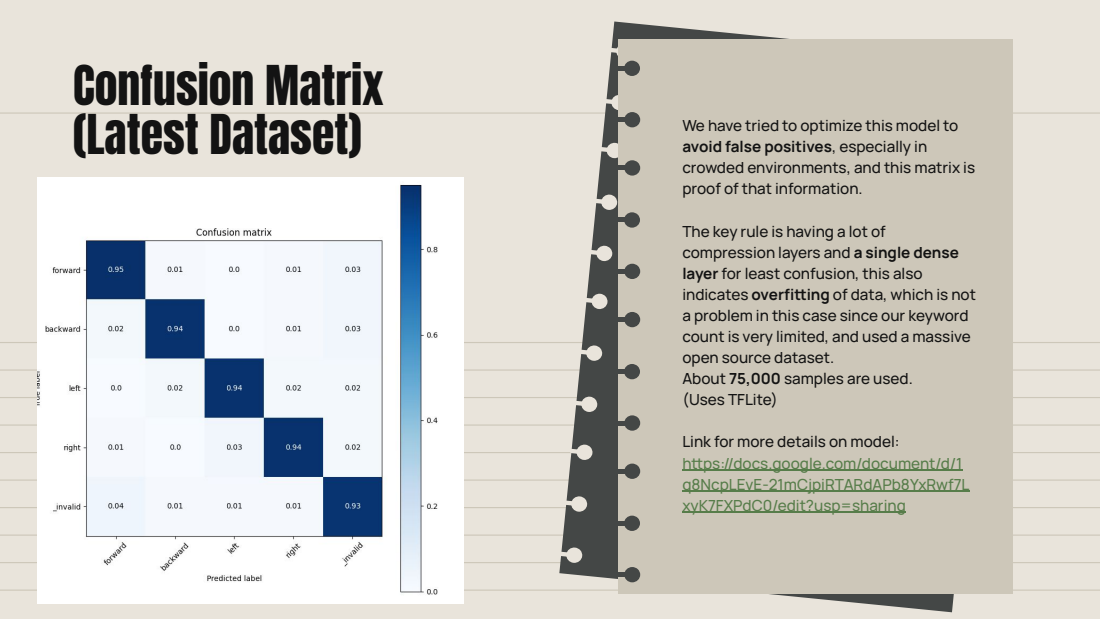
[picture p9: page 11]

We have tried to optimize this model to
avoid false positives, especially in
crowded environments, and this matrix is
proof of that information.

The key rule is having a lot of
compression layers and a single dense
layer for least confusion, this also
indicates overfiing of data, which is not
a problem in this case since our keyword
count is very limited, and used a massive
open source dataset.
About 75,000 samples are used.
(Uses TFLite)

Link for more details on model:
hps://docs.google.com/document/d/1
q8NcpLEvE-21mCjpiRTARdAPb8YxRwf7L
xyK7FXPdC0/edit?usp=sharing (https://docs.google.com/document/d/1q8NcpLEvE-21mCjpiRTARdAPb8YxRwf7LxyK7FXPdC0/edit?usp=sharing)

# Implementation Challenges

### - Mic not being consistent with time - Having a lot of false positives towards the end of timeline due to the possible reasons

■ | Noise from PCB connections
■ | Mic having unregulated voltage
■ | Dust collection

### - Cannot make the Model larger otherwise it would start eating up FreeRTOS memory - Confusion, and Accuracy Matrix are theoretical values only - Previously recorded Real Accuracy values seem to have decreased significantly

- All the above implies addition of extra Noise in the mic input making our bot move like a ghost

### (false positives)

### Added A gating mechanism - To reduce ambient sound/noise readings from surroundings or mic leading to false positives, we gate the inputs to the model based on input thresholds which will give only possible words to the model leading to significantly lesser false positives

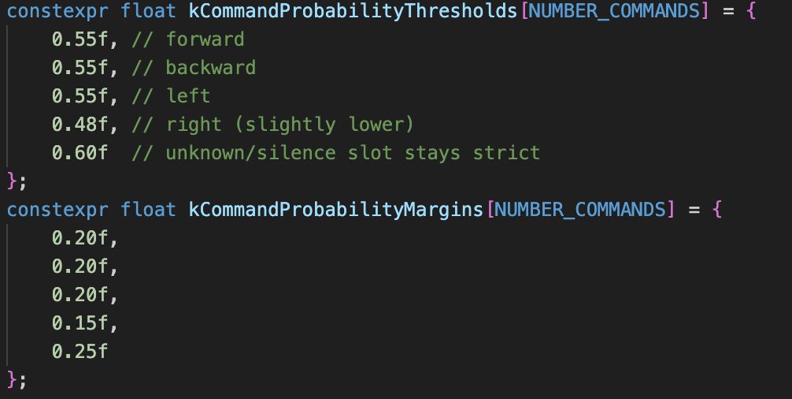
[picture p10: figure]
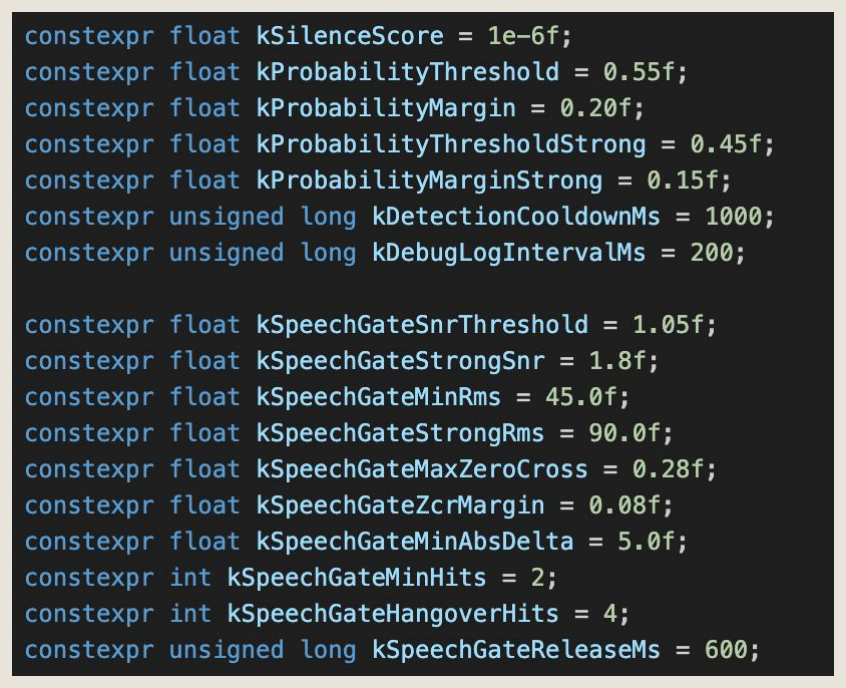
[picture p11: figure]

### - Set by real life testing and approximations

# Noise Filtering For Mic Inputs

### Best Score Filtering

- Once the gate passes an audio sample,

### Then for each of these commands, we set a custom threshold for the probability vector of the output to

determine its action.

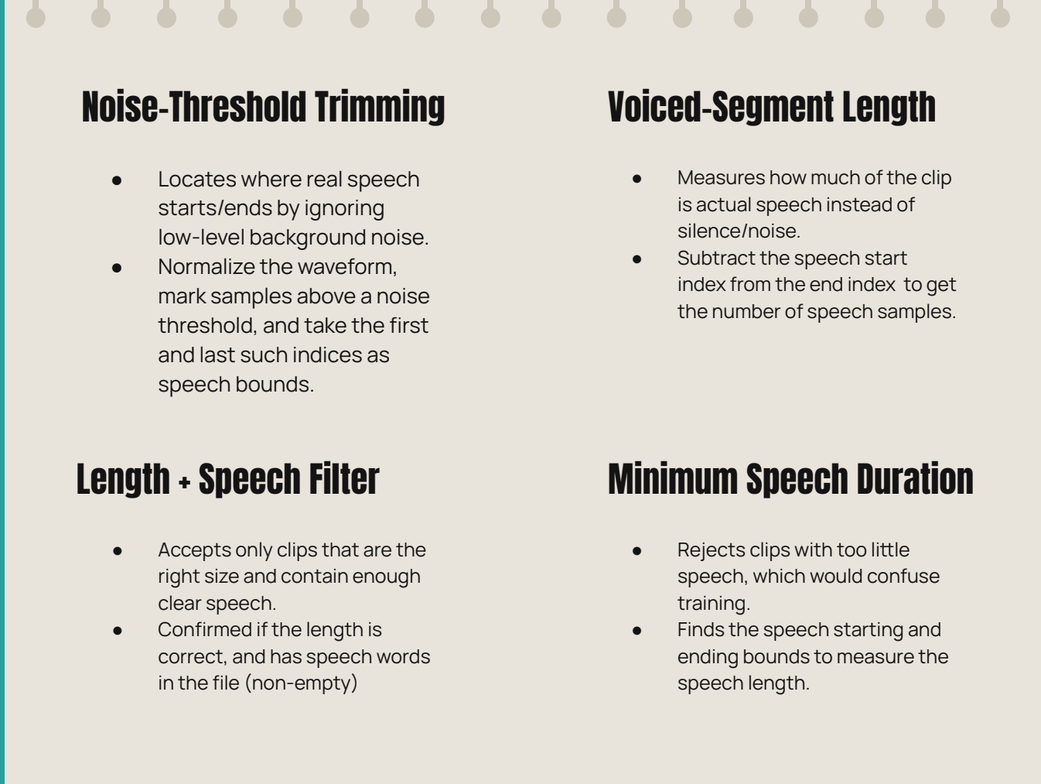
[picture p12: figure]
Noise-Threshold Trimming; ● Measures how much of the clip is actual speech instead of silence/noise. ● Subtract the speech start index from the end index to get the number of speech samples.; Voiced-Segment Length; Length + Speech Filter; ● Rejects clips with too lile speech, which would confuse training. ● Finds the speech starting and ending bounds to measure the speech length.; Minimum Speech Duration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

# Data Sample Filtering

# Audio Classifica

tion | To evaluate the audio recognition capacities of our bot we did classification in dierent scenarios, we measured the decibels near the speaker, and near the microphone on the microbot, we also measured the ambient decibels in the setup and the distance between the speaker and the bot. For each set up we measured the values multiple times and took the average and rounded o to the nearest integer.
Scenario | Speaker db | Microbot db | Ambient db | Distance
Little ambient noise | 88 | 66 | 60 | 1.25m
Little ambient noise | 90 | 68 | 61 | 2.6m
Little ambient noise | 91 | 67 | 60 | 5m
Noisy (multiple conversations) | 92 | 72 | 68 | 2m
Noisy (multiple conversations) | 93 | 76 | 70 | 5m
Very Noisy | 95 | 82 | 77 | 1.5m
Echo bound | 92 | 73 | 65 | 2m

## INMP441 I²

## S mic

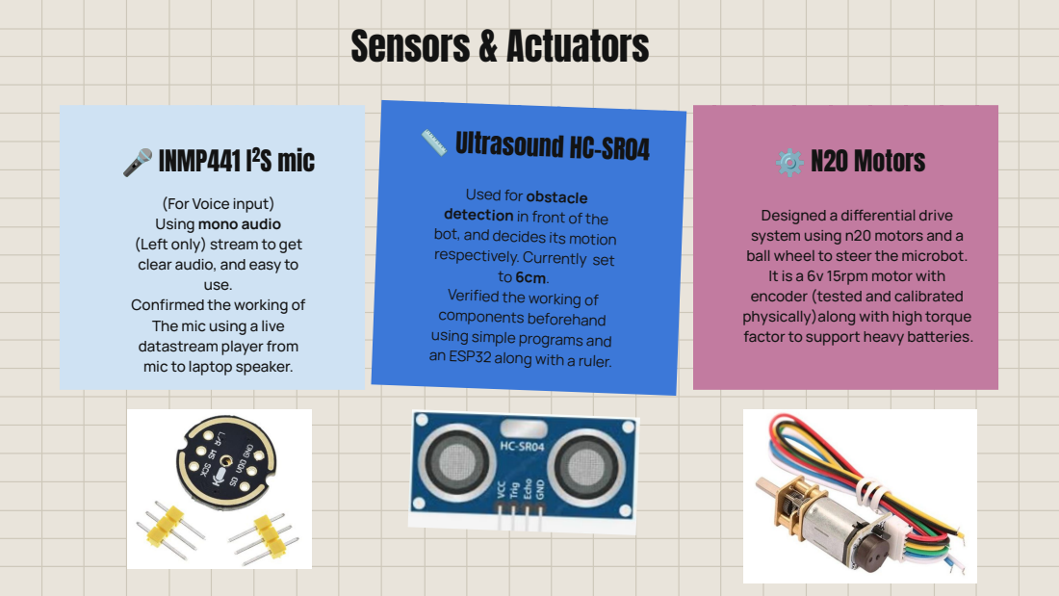
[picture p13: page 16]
use.; Sensors & Actuators; components beforehand

Ultrasound HC-SR04 N20 Motors

(For Voice input)
Using mono audio
(Left only) stream to get
clear audio, and easy to

Used for obstacle

detection in front of the

Designed a dierential drive
system using n20 motors and a
ball wheel to steer the microbot.
It is a 6v 15rpm motor with
encoder (tested and calibrated
physically)along with high torque
factor to support heavy baeries.

bot, and decides its motion

respectively. Currently set

Verified the working of

Confirmed the working of
The mic using a live
datastream player from
mic to laptop speaker.

using simple programs and

an ESP32 along with a ruler.

## ESP32-S3 & ESP32

## current sensor + buck

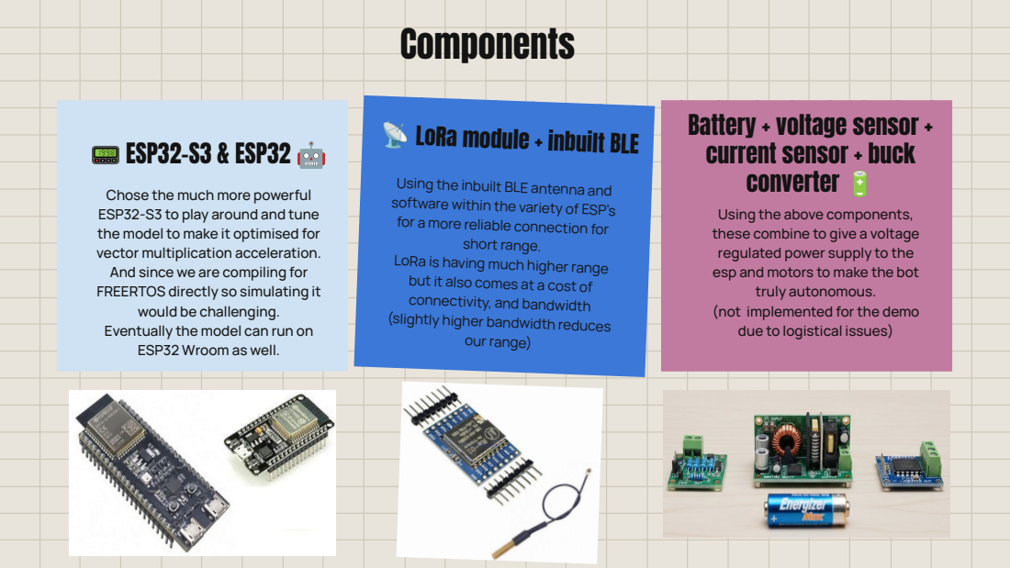
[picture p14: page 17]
converter; Components; short range.; our range)

LoRa module + inbuilt BLE Battery + voltage sensor +

Using the inbuilt BLE antenna and

Chose the much more powerful
ESP32-S3 to play around and tune
the model to make it optimised for
vector multiplication acceleration.
And since we are compiling for
FREERTOS directly so simulating it
would be challenging.
Eventually the model can run on
ESP32 Wroom as well.

software within the variety of ESP’s

Using the above components,
these combine to give a voltage
regulated power supply to the
esp and motors to make the bot
truly autonomous.
(not implemented for the demo
due to logistical issues)

for a more reliable connection for

LoRa is having much higher range

but it also comes at a cost of

connectivity, and bandwidth

(slightly higher bandwidth reduces

## Block Diagram

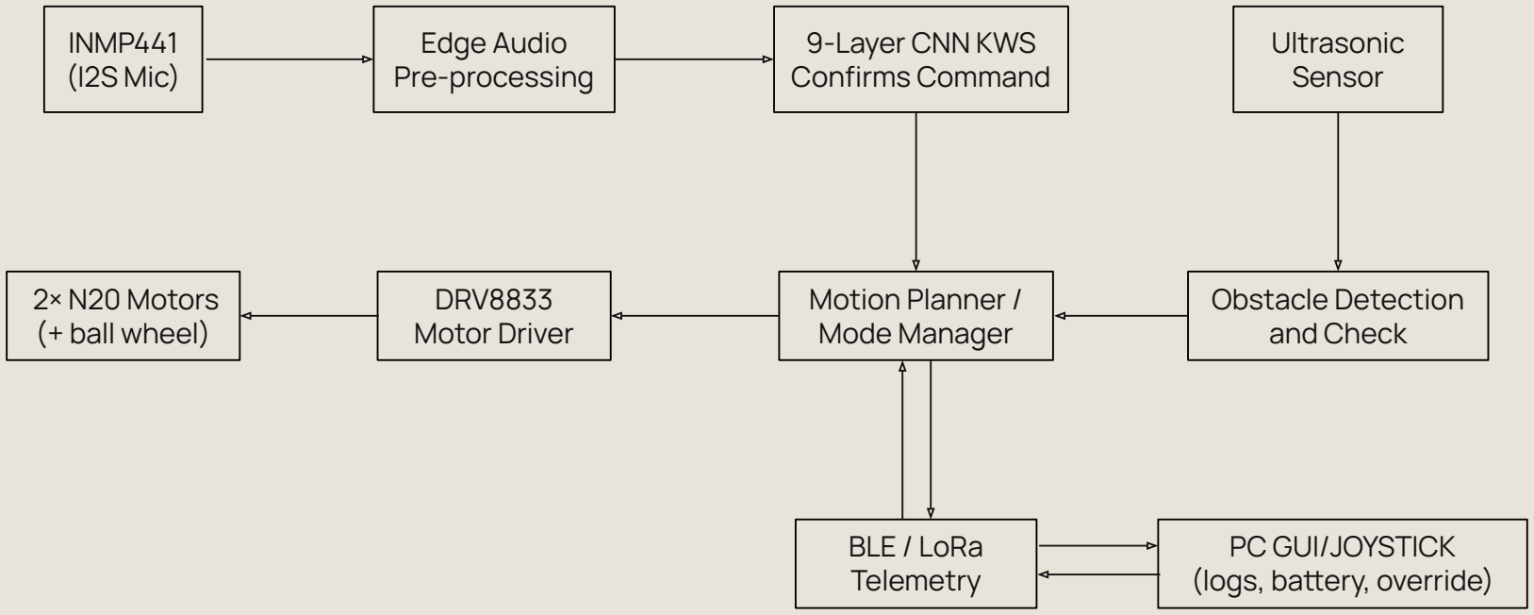
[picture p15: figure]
INMP441 (I2S Mic); Edge Audio Pre‑processing; 9‑Layer CNN KWS Confirms Command; Ultrasonic Sensor; Obstacle Detection and Check; Motion Planner / Mode Manager; DRV8833 Motor Driver; 2× N20 Motors (+ ball wheel); BLE / LoRa Telemetry; PC GUI/JOYSTICK (logs, baery, override)

## Audio Path I2S mic

## UltraSonic Sensor

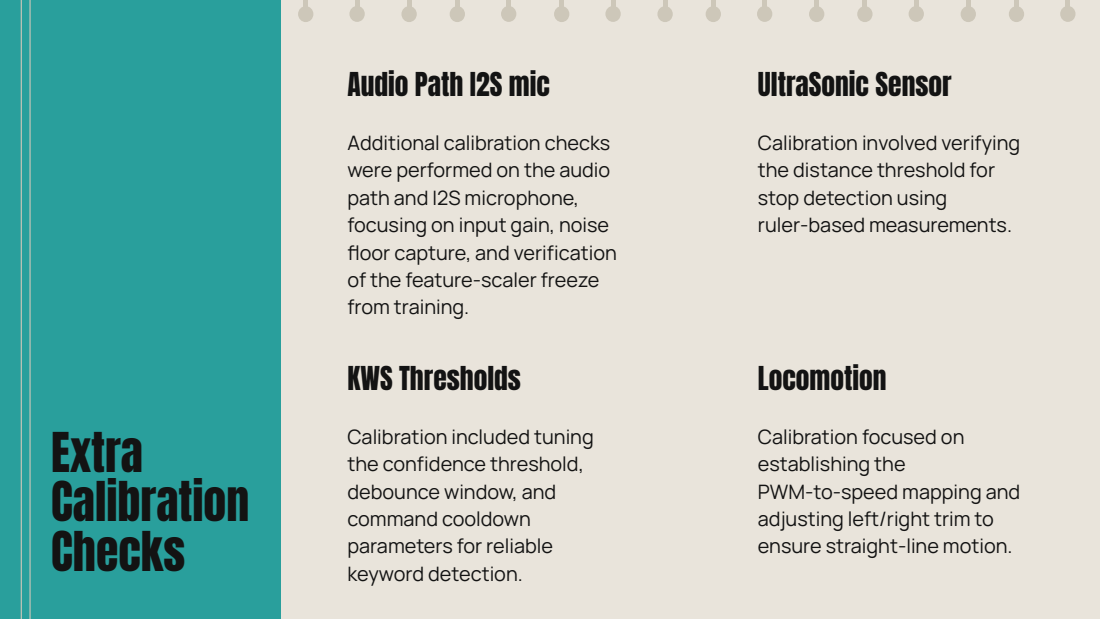
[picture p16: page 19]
Extra Calibration Checks; KWS Thresholds; Locomotion

Additional calibration checks
were performed on the audio
path and I2S microphone,
focusing on input gain, noise
floor capture, and verification
of the feature-scaler freeze
from training.

Calibration involved verifying
the distance threshold for
stop detection using
ruler-based measurements.

Calibration included tuning
the confidence threshold,
debounce window, and
command cooldown
parameters for reliable
keyword detection.

Calibration focused on
establishing the
PWM-to-speed mapping and
adjusting left/right trim to
ensure straight-line motion.

# Hardware

# (The Microbot)

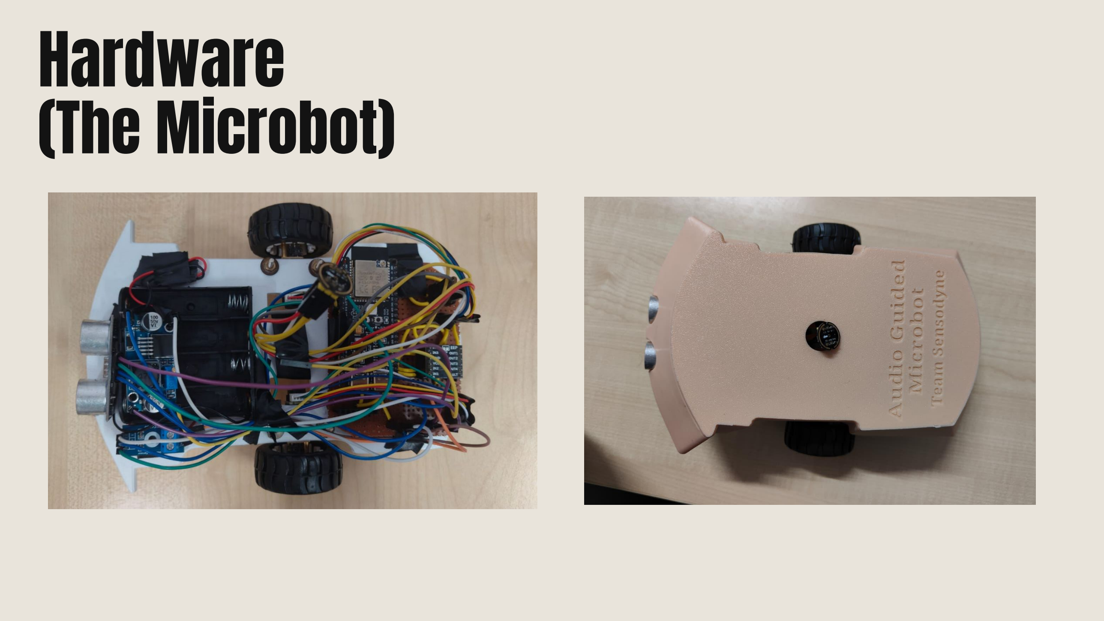
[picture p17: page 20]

# PCB

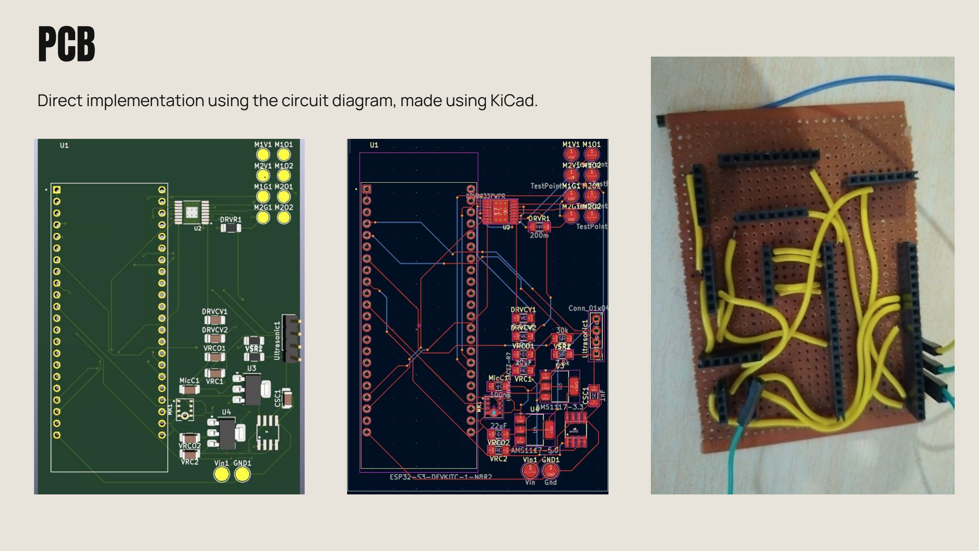
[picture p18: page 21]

Direct implementation using the circuit diagram, made using KiCad.

# 3D Model

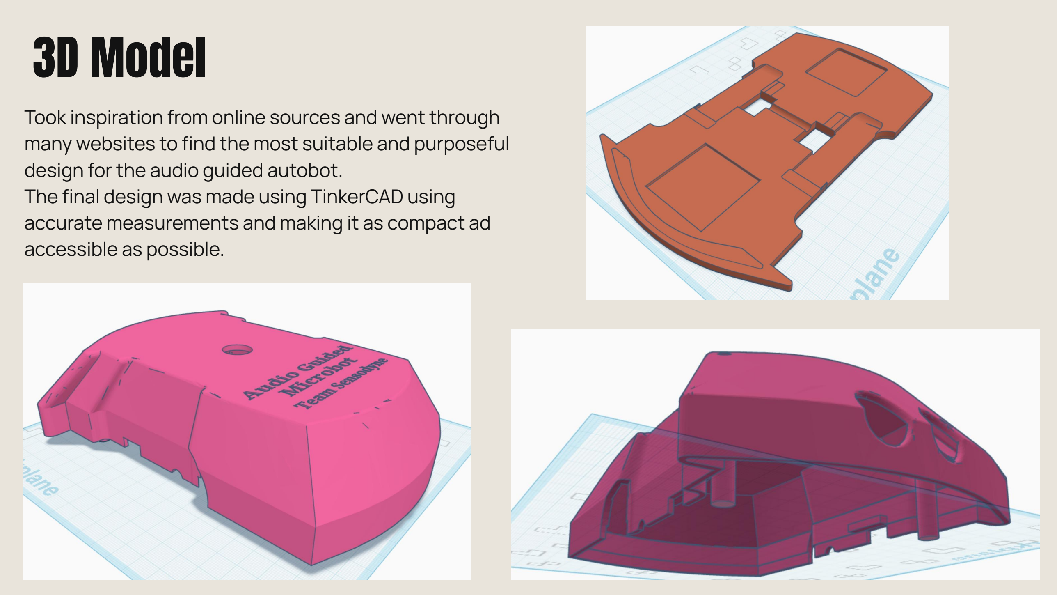
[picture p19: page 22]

Took inspiration from online sources and went through many websites to find the most suitable and purposeful design for the audio guided autobot.
The final design was made using TinkerCAD using accurate measurements and making it as compact ad accessible as possible.

# Circuit Schematic

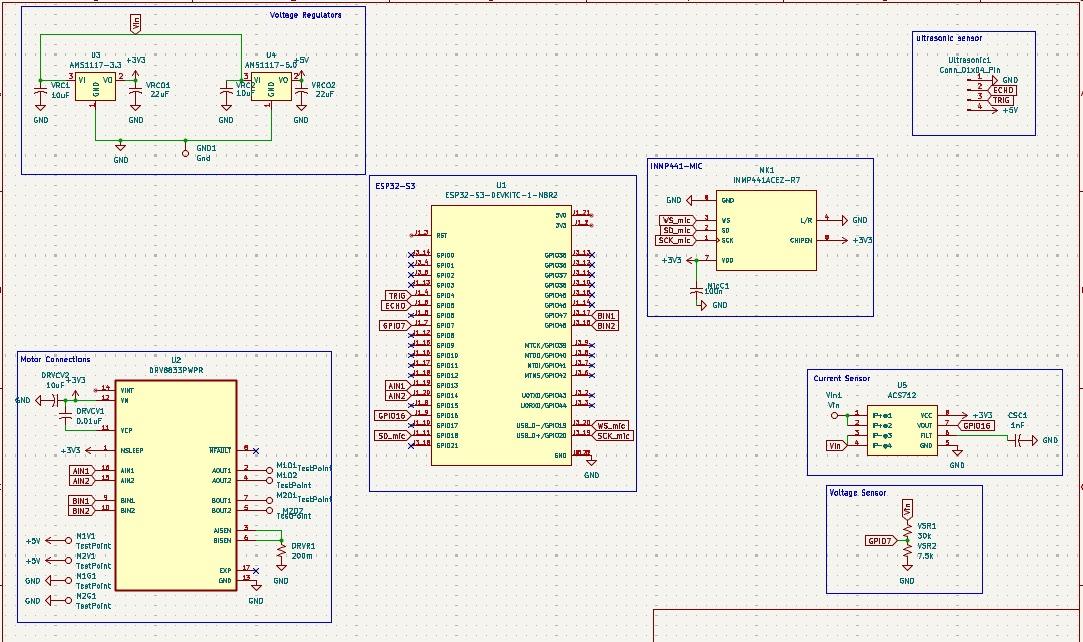
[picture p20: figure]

# Battery Life

Motor Runtime | Avg. Current (A) | Runtime (h) | hh:mm
0% | 0.18 | ~3.50 | ~3h 30m
25% | 0.198 | ~3.00 | ~3h 00m
50% | 0.215 | ~2.75 | ~2h 45m
75% | 0.232 | ~2.50 | ~2h 30m
100% | 0.25 | ~2.25 | ~2h 15m

To evaluate the endurance of our microbot, we measured its current consumption at dierent levels of movement activity. As expected, increased motion leads to a proportional rise in average current draw, which directly shortens the available runtime.

These tests were conducted using 4 AA baeries (each of 1.3V with 600mah capacity) with total 5.2V (in series) under consistent operating conditions, with the microbot performing repeated movement cycles to ensure reliable measurements.

For Power Optimization, (Hardware) Implemented DRV Sleep Mode to cut motor driver power when idle, (Software) Added Audio Gating to stop the AI from processing silence/noise, significantly reducing CPU load and power consumption.

# Remote GUI

- Connects to the ESP32 microbot over serial and shows real-time logs.
- Manual Override: toggles voice control o and hands control to the GUI.
- Drive controls: buons & arrow keys for Forward / Backward / Left / Right, or Use a Controller
- Shows motion state
(color-coded: FORWARD /
BACKWARD / LEFT / RIGHT / IDLE).
- Live telemetry: baery voltage and current draw with a small live graph.
- Displays approximate speed (no-slip estimate).

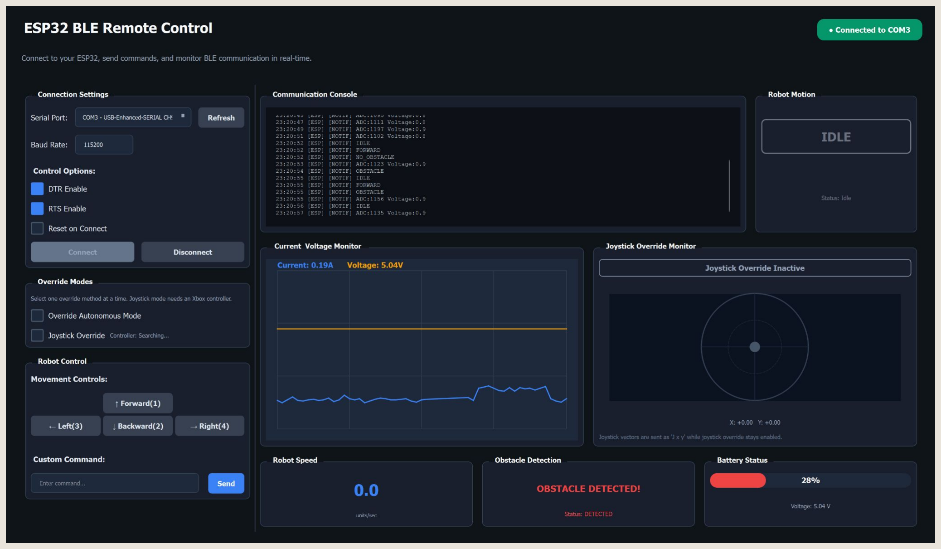
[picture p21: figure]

- Obstacle status: clear vs OBSTACLE DETECTED (auto switches to IDLE on detect).
- Send custom commands directly from the input box.
- Also shows the joystick input after validation, and transmits it successfully

# Joystick Implementation

An Extra Feature of to bot: Real-Time Bot Control Using Joystick Interface

- Added real-time robot motion control using a Bluetooth-connected joystick for precise movement.
- Implemented a Python GUI to read joystick values and visualize motion.
- GUI sends continuous 2-axis vector commands (Jx,y) over BLE.
- ESP32 converts joystick vector into differential motor speeds.
- Enabling us to control the bot in 8 directions, and analog speeds

Read actual joystick hardware
(controller), analysing and plotting it
in gui and then sending the vectorized signals (Jx,y) to the microbot for actual motion via the Bluetooth connection, everything done by using python libraries (like Pygame).
- Measuring X and Y coordinate between -1 and 1 for precise movement
Direction of motion of motors is calculated according to coordinates.

Converting motor speed to PWM: PWM Duty= |Speed|×255
(Positive value → forward pin Negative value → reverse pin Zero → motor stops)

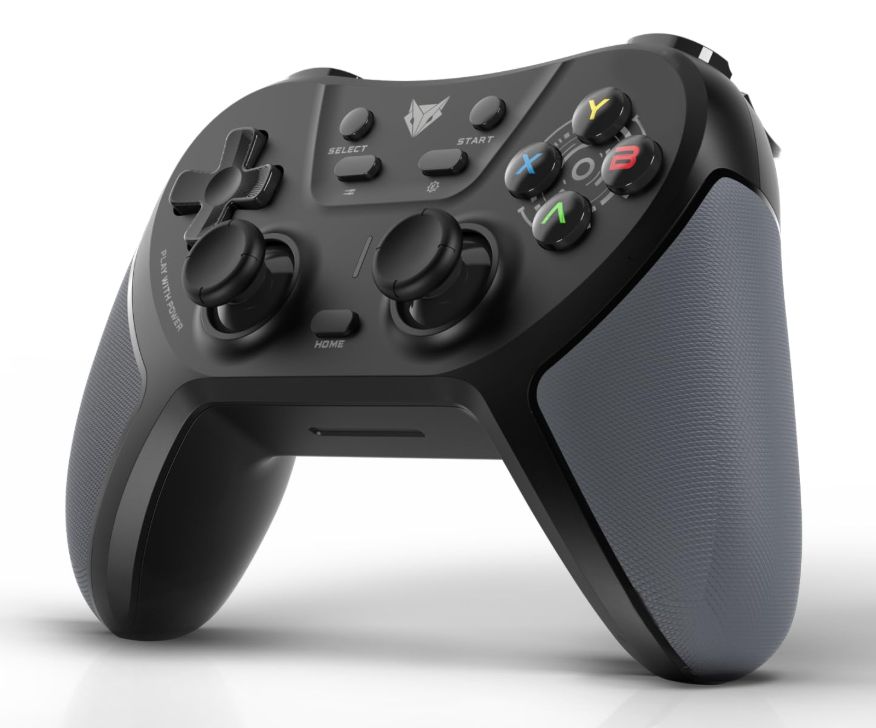
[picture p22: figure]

- Smooth acceleration and
turning.
- Full 360° joystick control.
- Differential turning
(tank-like steering).
- Live motion with no
noticeable delay.
- Automatic stop when no
joystick data for 400ms
(safety timeout).

Joystick → (x,y) → simple formulas → left/right speeds → PWM → motors

# Network Communication Classification

# LoRa v/s BLE

## To help decide the network protocol in the early stages of the project we performed Characterisation of LoRa and BLE communications. We tested

## the signal strength and communication reliability in

## dierent setups, which took into consider factors that could cause disturbance in

communication like distance,

## walls, metal doors, echo, and interference from other

devices.

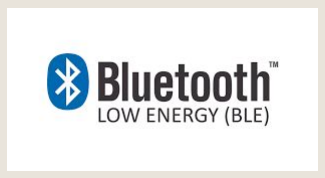
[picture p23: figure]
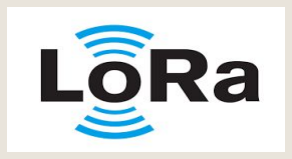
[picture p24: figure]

Range(m) | Inference
0m (DOS) | ✔ | Reliable Communication
30m (DOS) | ✔ | Reliable Communication
30m (echoey hallway) (DOS) | ✔ | Reliable Communication
50m (echoey hallway) (DOS) | ✘ Limiting Communication
70m (DOS) | ✔ | Reliable Communication
100m (DOS) | ✘ Limiting Communication
20m (two walls in between) | ✘ Limiting Communication

# BLE Classification Inferences (with top cover)

DOS- Direct Line of SIght. Using esp32 and esp32S3.

Range(m) | Inference
Start at 0m and fast movement upto 30m | ✔ | Reliable Communication
Fast movement upto 50m | ✘ | Limiting Communication
Slow movement upto 60m with no DOS. | ✔ | Reliable Communication
Slow movement with DOS upto 85m | ✔ | Reliable Communication
15m (2 metal doors) | ✘ Communication disrupts as 2nd door introduced
Introducing movement and objects at 100m | ✘ Unstable Communication

# BLE Classification Inferences (with top cover)

DOS- Direct Line of SIght. Using esp32 and esp32S3.

## Fast movement: running, Slow movement: approx. speed of bot

# LoRa Classification Inferences

## DOS- Direct Line of SIght

Range(m) | Inference
0m (DOS) | ✔ | Reliable Communication
15m (3rd floor to ground floor) | ✘ Unreliable Communication
20m (2 metal doors) | ✔ | Reliable Communication
50m (few walls in between) | ✔ | Reliable Communication
110m (echoey Hallway) | ✘ Unstable Communication
100m (DOS) | ✔ | Reliable Communication
175m (DOS) | ✔ | Reliable Communication
254m (DOS) | ✘ Communication Terminates

# Encrypted LoRa Communication

To ensure secure communication we performed encryption over LoRa communication. We used Elliptic Curve Diie-Hellman and AES-256 encryption. Each device creates a unique pair of keys, one private and one public. The two devices exchange their public keys and derive a shared secret key using ECDH (Elliptic Curve Diie-Hellman). The shared key is used for AES-256 encryption to lock data before transmission. The receiver unlocks and verifies the authentication tag.

Initial

Exchange of Public
Keys

Let Devices A and B. They
Generate key pairs, (PrA,
PuA) and (PrB, PuB)
respectively. They exchange PuA and PuB.

Shared Secret Key
generation

The shared secret key(Ks)
is derived using ECDH as
Ks=f(PuB,PrA,Prime)
Ks=f(PuA,PrB,Prime)

Derivation

Encryption and
Transmission of Data

The data is locked using
AES-256 encryption and
then transmitted.

Encryption

Decryption and
Verification

The data is decrypted
using the shared secret
key and the Authentication Tag is verified

Decryption

# Challenges Faced

### Change in problem statement

- Our initial approach required detecting the direction of sound using multiple microphones and applying beamforming, vectorization, and triangulation.
- Beamforming is complex because it depends on precise time-of-arrival dierences in sound between microphones. Even tiny errors in spacing, synchronization, or noise break the calculations.
- All mics need to be calibrated correctly and synchronized which is very challenging.
- Our hardware setup (ESP32 + low-quality mics + no synchronized ADC sampling) was not capable of the precision needed.
- Debugging was extremely time-consuming because direction detection needs:
- calibrated microphone spacing
- stable phase alignment
- high-quality simultaneous audio sampling
- clean signals with minimal noise
- After spending a major portion of time, we still couldn’t get reliable direction estimates, and the problem statement itself was later changed, making this entire eort a heavy time investment with no final output.

# Challenges Faced

### ML Model Creation & Edge Impulse Failures (Audio-Guided Microbot)

- Due to ESP32 memory limits, our model had to be extremely small (few kB), which made training very restrictive.
- We tried multiple solutions — custom datasets, pre-trained models, and many Edge Impulse pipelines — but most models either did not fit or had insuicient accuracy.
- The Edge Impulse model worked perfectly on their website and in the browser test, but the moment we deployed it on the ESP32, it stopped working.
- To debug this, we streamed raw mic audio to a laptop via serial and tested with:
- Python audio playback (proved the mic input was OK)
- Whisper-tiny in real-time (also worked well)
- This confirmed: the mic and data were fine, the ESP was the issue.
- Despite all this, we never found the root cause of the failure on the device — the model simply refused to run properly once flashed.
- This consumed a massive amount of time across many days.
- (We eventually solved it using a manual .tflite model + TFLite-Micro, so the solution is not listed as a challenge — the diiculty was the long process before reaching it.)

Microphone Noise & Threshold Tuning
- The microphone produced unpredictable noise (possibly PCB/soldering issues/dust accumulation).
- Noise caused false positives, and raising thresholds caused false negatives — tuning was extremely sensitive.
- This instability made the model output unreliable.
Early Hardware Instability (Breadboard Phase)
- Wires frequently disconnected during tests.
- One breadboard power line was internally faulty, causing random non-working circuits.
- Loose connections slowed debugging significantly.
Joystick Control Issue (GPIO Conflict with NeoPixel)
- On the ESP32-S3, both the motors and the NeoPixel LED were using GPIO 48.
- For simple commands (forward/back/left/right), both worked fine.
- But during joystick mode (full 360° control + dynamic RGB color), the NeoPixel timing interfered with motor control, causing the motors to stop working.
- Removing the RGB LED (not needed once we added an enclosure) fixed the issue — motors then responded perfectly.

# Challenges Faced

# THANK YOU!

(Don’t forget to brush)

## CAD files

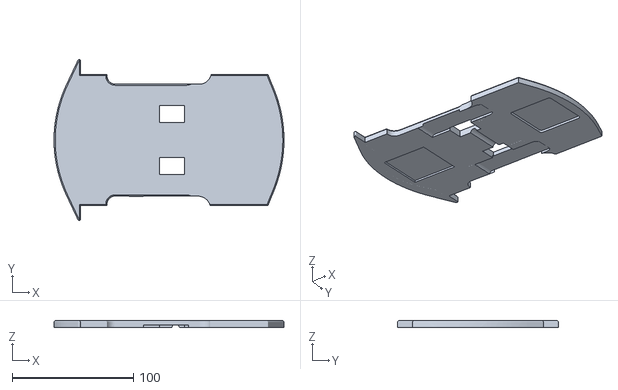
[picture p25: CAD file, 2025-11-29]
Code/3d_Models/Base_plate.stl
190.0 x 133.1 x 5.60

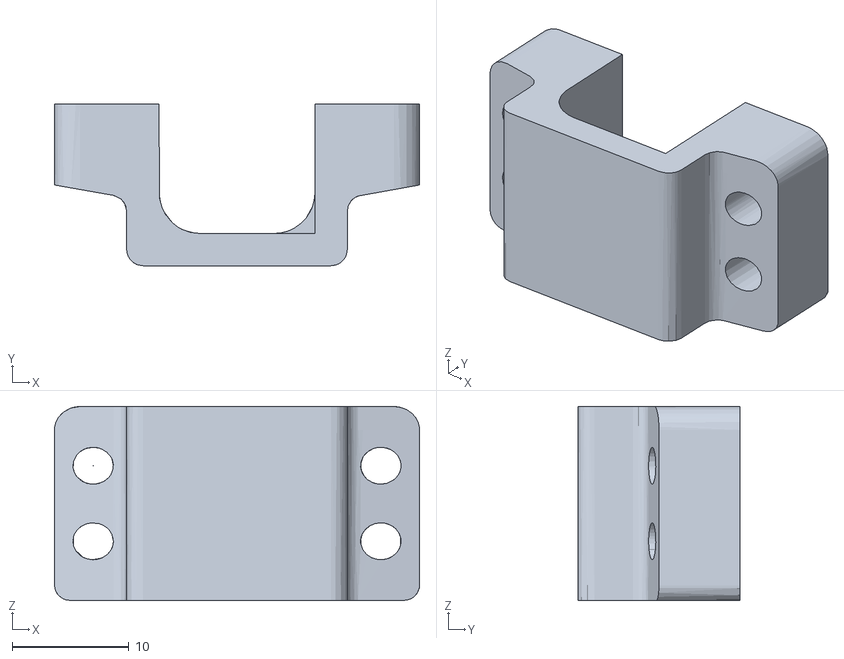
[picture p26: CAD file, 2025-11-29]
Code/3d_Models/n20_holders.stl
31.3 x 13.9 x 16.6

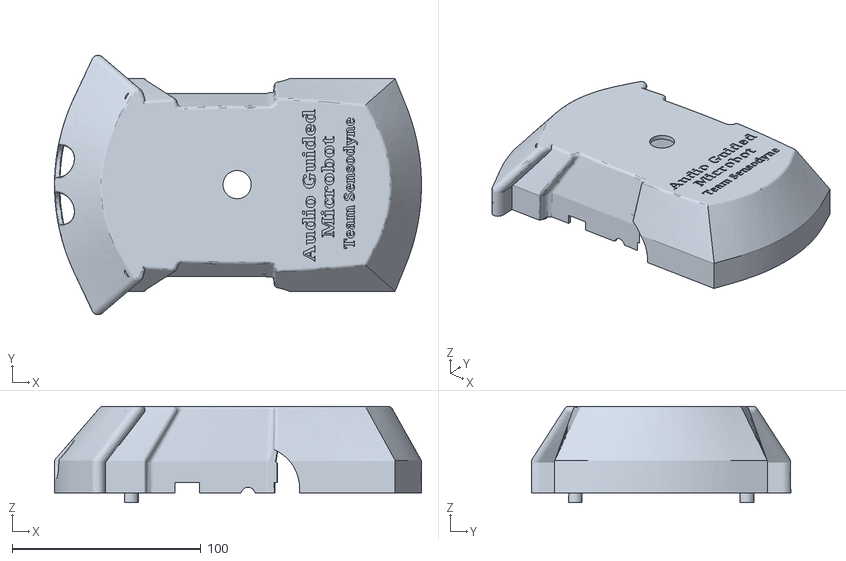
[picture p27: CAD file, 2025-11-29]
Code/3d_Models/Top_cover.stl
194.6 x 137.6 x 51.0

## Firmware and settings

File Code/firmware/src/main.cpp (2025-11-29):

#include <Arduino.h>
#include <WiFi.h>
#include <driver/i2s.h>
#include <esp_task_wdt.h>
#include <math.h>
#include "I2SMicSampler.h"
// #include "ADCSampler.h"
#include "config.h"
#include "CommandDetector.h"
#include "CommandProcessor.h"
#include "ble_commands.h"
// ...existing code...
#include "neopixel_motorpin.h"

extern BleCommands BLECmd;
// #include "obstacle.h"
// #define TRIG_PIN 4
// #define ECHO_PIN 5

BleCommands BLECmd;
int flag = 1;
static volatile bool g_bleReady = false;
static bool g_controllerMode = false;
static bool g_pwmAttached = false;
static uint32_t g_lastVectorMs = 0;

constexpr uint8_t CONTROLLER_MODE_CODE = 6;
constexpr uint32_t CONTROLLER_TIMEOUT_MS = 400;
constexpr float JOYSTICK_DEADBAND = 0.08f;
constexpr uint8_t LEDC_LEFT_FWD_CHANNEL = 0;
constexpr uint8_t LEDC_LEFT_REV_CHANNEL = 1;
constexpr uint8_t LEDC_RIGHT_FWD_CHANNEL = 2;
constexpr uint8_t LEDC_RIGHT_REV_CHANNEL = 3;
constexpr uint32_t LEDC_PWM_FREQ = 20000;
constexpr uint8_t LEDC_PWM_RES_BITS = 8;

static void attachMotorPwm();
static void detachMotorPwm();
static void applyMotorSpeed(float value, uint8_t forwardChannel, uint8_t reverseChannel);
static void driveWithVector(float x, float y);
static void stopControllerMotion();
static void handleJoystickVector(float x, float y);

constexpr uint8_t SENSOR_PIN = 7; // GPIO7 / ADC1_CH6 on ESP32-S3 for voltage
constexpr float ADC_REF_VOLTAGE = 3.3f;
constexpr uint16_t ADC_FULL_SCALE = 4095;

// i2s config for reading from both channels of I2S
i2s_config_t i2sMemsConfigBothChannels = {
    .mode = (i2s_mode_t)(I2S_MODE_MASTER | I2S_MODE_RX),
    .sample_rate = 16000,
    .bits_per_sample = I2S_BITS_PER_SAMPLE_32BIT,
    .channel_format = I2S_MIC_CHANNEL,
    .communication_format = i2s_comm_format_t(I2S_COMM_FORMAT_STAND_I2S),
    .intr_alloc_flags = ESP_INTR_FLAG_LEVEL1,
    .dma_buf_count = 4,
    .dma_buf_len = 64,
    .use_apll = false,
    .tx_desc_auto_clear = false,
    .fixed_mclk = 0};

// i2s microphone pins
i2s_pin_config_t i2s_mic_pins = {
    .bck_io_num = I2S_MIC_SERIAL_CLOCK,
    .ws_io_num = I2S_MIC_LEFT_RIGHT_CLOCK,
    .data_out_num = I2S_PIN_NO_CHANGE,
    .data_in_num = I2S_MIC_SERIAL_DATA};

static void attachMotorPwm()
{
  if (g_pwmAttached)
  {
    return;
  }

  ledcSetup(LEDC_LEFT_FWD_CHANNEL, LEDC_PWM_FREQ, LEDC_PWM_RES_BITS);
  ledcSetup(LEDC_LEFT_REV_CHANNEL, LEDC_PWM_FREQ, LEDC_PWM_RES_BITS);
  ledcSetup(LEDC_RIGHT_FWD_CHANNEL, LEDC_PWM_FREQ, LEDC_PWM_RES_BITS);
  ledcSetup(LEDC_RIGHT_REV_CHANNEL, LEDC_PWM_FREQ, LEDC_PWM_RES_BITS);

  ledcAttachPin(IN1, LEDC_LEFT_FWD_CHANNEL);
  ledcAttachPin(IN2, LEDC_LEFT_REV_CHANNEL);
  ledcAttachPin(IN4, LEDC_RIGHT_FWD_CHANNEL);
  ledcAttachPin(IN3, LEDC_RIGHT_REV_CHANNEL);

  ledcWrite(LEDC_LEFT_FWD_CHANNEL, 0);
  ledcWrite(LEDC_LEFT_REV_CHANNEL, 0);
  ledcWrite(LEDC_RIGHT_FWD_CHANNEL, 0);
  ledcWrite(LEDC_RIGHT_REV_CHANNEL, 0);

  g_pwmAttached = true;
}

static void detachMotorPwm()
{
  if (!g_pwmAttached)
  {
    return;
  }

  ledcDetachPin(IN1);
  ledcDetachPin(IN2);
  ledcDetachPin(IN3);
  ledcDetachPin(IN4);

  digitalWrite(IN1, LOW);
  digitalWrite(IN2, LOW);
  digitalWrite(IN3, LOW);
  digitalWrite(IN4, LOW);
  digitalWrite(DRV_EEP, LOW);

  g_pwmAttached = false;
}

static void applyMotorSpeed(float value, uint8_t forwardChannel, uint8_t reverseChannel)
{
  if (value > 1.0f)
  {
    value = 1.0f;
  }
  else if (value < -1.0f)
  {
    value = -1.0f;
  }

  float magnitude = fabsf(value);
  uint32_t duty = static_cast<uint32_t>(magnitude * ((1u << LEDC_PWM_RES_BITS) - 1u));

  if (value > 0.0f)
  {
    ledcWrite(forwardChannel, duty);
    ledcWrite(reverseChannel, 0);
  }
  else if (value < 0.0f)
  {
    ledcWrite(forwardChannel, 0);
    ledcWrite(reverseChannel, duty);
  }
  else
  {
    ledcWrite(forwardChannel, 0);
    ledcWrite(reverseChannel, 0);
  }
}

static float clampUnit(float value)
{
  if (value > 1.0f) return 1.0f;
  if (value < -1.0f) return -1.0f;
  return value;
}

static float applyJoystickDeadband(float value)
{
  return (fabsf(value) < JOYSTICK_DEADBAND) ? 0.0f : value;
}

static void driveWithVector(float x, float y)
{
  if (!g_controllerMode)
  {
    return;
  }

  if (!g_pwmAttached)
  {
    attachMotorPwm();
  }

  float xInput = applyJoystickDeadband(clampUnit(x));
  float yInput = applyJoystickDeadband(clampUnit(y));
  float forward = yInput;
  float turn = -xInput; // invert to align joystick X with robot's turning direction
  float left = forward + turn;
  float right = forward - turn;

  float limit = fmaxf(fabsf(left), fabsf(right));
  if (limit > 1.0f)
  {
    left /= limit;
    right /= limit;
  }

  float magnitude = clampUnit(sqrtf((xInput * xInput) + (yInput * yInput)));
  left *= magnitude;
  right *= magnitude;

  applyMotorSpeed(left, LEDC_LEFT_FWD_CHANNEL, LEDC_LEFT_REV_CHANNEL);
  applyMotorSpeed(right, LEDC_RIGHT_FWD_CHANNEL, LEDC_RIGHT_REV_CHANNEL);

  bool moving = (fabsf(left) > 0.001f) || (fabsf(right) > 0.001f);
  digitalWrite(DRV_EEP, moving ? HIGH : LOW);

  g_lastVectorMs = millis();
}

static void stopControllerMotion()
{
  if (g_pwmAttached)
  {
    ledcWrite(LEDC_LEFT_FWD_CHANNEL, 0);
    ledcWrite(LEDC_LEFT_REV_CHANNEL, 0);
    ledcWrite(LEDC_RIGHT_FWD_CHANNEL, 0);
    ledcWrite(LEDC_RIGHT_REV_CHANNEL, 0);
  }
  digitalWrite(IN1, LOW);
  digitalWrite(IN2, LOW);
  digitalWrite(IN3, LOW);
  digitalWrite(IN4, LOW);
  digitalWrite(DRV_EEP, LOW);

}

// This task does all the heavy lifting for our application
void applicationTask(void *param)
{
  CommandDetector *commandDetector = static_cast<CommandDetector *>(param);

  const TickType_t xMaxBlockTime = pdMS_TO_TICKS(100);
  while (true)
  {
    // wait for some audio samples to arrive
    uint32_t ulNotificationValue = ulTaskNotifyTake(pdTRUE, xMaxBlockTime);
    if (ulNotificationValue > 0)
    {
      commandDetector->run();
    }
  }
}

static void handleJoystickVector(float x, float y)
{
  Serial.printf("[BLE] Joystick vector callback x=%.3f y=%.3f (controller %s)\n", x, y, g_controllerMode ? "ON" : "OFF");
  if (!g_controllerMode)
  {
    Serial.println("[BLE] Ignoring joystick vector because controller mode is OFF");
    return;
  }

  if (x < -1.0f) x = -1.0f;
  if (x > 1.0f) x = 1.0f;
  if (y < -1.0f) y = -1.0f;
  if (y > 1.0f) y = 1.0f;

  driveWithVector(x, y);
}

void handleCode(int code){
  Serial.printf("[RX] Received code: %d\n", code);

  if (code == CONTROLLER_MODE_CODE)
  {
    if (!g_controllerMode)
    {
      g_controllerMode = true;
      attachMotorPwm();
      stopControllerMotion();
      g_lastVectorMs = millis();
      flag = 0;
      BLECmd.notify("MODE:CONTROLLER_ON");
    }
    else
    {
      stopControllerMotion();
      detachMotorPwm();
      g_controllerMode = false;
      flag = 1;
      BLECmd.notify("MODE:CONTROLLER_OFF");
    }
    return;
  }

  if(code==0){
    if (g_controllerMode)
    {
      stopControllerMotion();
      detachMotorPwm();
      g_controllerMode = false;
      flag = 1;
      BLECmd.notify("MODE:CONTROLLER_OFF");
    }

    if(flag == 0){
      flag = 1;
    }
    else{
      flag = 0;
    }
    return;
  }

  if (g_controllerMode)
  {
    Serial.println("[RX] Ignoring direct motor command while joystick controller mode is active");
    return;
  }
  else if(code==1 && !flag){
    Serial.println("Forward");
    pinMode(4, OUTPUT);
    pinMode(5, INPUT);
    digitalWrite(4, LOW);
    delayMicroseconds(2);
    digitalWrite(4, HIGH);
    delayMicroseconds(10);
    digitalWrite(4, LOW);
    long duration = pulseIn(5, HIGH, 20000);
    float d = 0;
    if(duration == 0){
        d = -1;
    }
    else{
        d = duration * 0.034 / 2.0;
    }
    Serial.print("Distance: ");
    Serial.print(d, 2);
    Serial.println("cm");
    if(d > 0 && d < 6.0){
      Serial.println("Obstacle detected! Stopping.");
      BLECmd.notify("OBSTACLE");
      vTaskDelay(1000 / portTICK_PERIOD_MS);
      digitalWrite(IN1, LOW);
      digitalWrite(IN2, LOW);
      digitalWrite(IN3, LOW);
      digitalWrite(IN4, LOW);
      BLECmd.notify("IDLE");
      return;
    }
    else{
      BLECmd.notify("NO_OBSTACLE");
      digitalWrite(DRV_EEP, HIGH);
    }
    digitalWrite(IN1, HIGH);
    digitalWrite(IN2, LOW);
    digitalWrite(IN3, LOW);
    digitalWrite(IN4, HIGH);
    // Obstacle detection in manual override
    digitalWrite(4, LOW);
    delayMicroseconds(2);
    digitalWrite(4, HIGH);
    delayMicroseconds(10);
    digitalWrite(4, LOW);
    for (int i = 0; i < 47; i++) {
      digitalWrite(4, LOW);
      delayMicroseconds(2);
      digitalWrite(4, HIGH);
      delayMicroseconds(10);
      digitalWrite(4, LOW);
      long duration = pulseIn(5, HIGH, 20000);
      float d = 0;
      if(duration == 0){
          d = -1;
      }
      else{
          d = duration * 0.034 / 2.0;
      }
      if(d > 0 && d < 6.0){
          Serial.println("Obstacle detected! Stopping.");
          BLECmd.notify("OBSTACLE");
          vTaskDelay(500 / portTICK_PERIOD_MS);
          break;
      }
      else{
        BLECmd.notify("NO_OBSTACLE");
      }
      vTaskDelay(pdMS_TO_TICKS(200));
    }
  }
  else if(code==2 && !flag){
    digitalWrite(DRV_EEP, HIGH);
    Serial.println("Backward");
    BLECmd.notify("NO_OBSTACLE");
    digitalWrite(IN1, LOW);
    digitalWrite(IN2, HIGH);
    digitalWrite(IN3, HIGH);
    digitalWrite(IN4, LOW);
    vTaskDelay(pdMS_TO_TICKS(5000));
  }
  else if(code==3 && !flag){
    digitalWrite(DRV_EEP, HIGH);
    Serial.println("Left");
    BLECmd.notify("NO_OBSTACLE");
    digitalWrite(IN1, HIGH);
    digitalWrite(IN2, LOW);
    digitalWrite(IN3, HIGH);
    digitalWrite(IN4, LOW);
    vTaskDelay(pdMS_TO_TICKS(5000));
  }
  else if(code==4 && !flag){
    digitalWrite(DRV_EEP, HIGH);
    Serial.println("Right");
    BLECmd.notify("NO_OBSTACLE");
    digitalWrite(IN1, LOW);
    digitalWrite(IN2, HIGH);
    digitalWrite(IN3, LOW);
    digitalWrite(IN4, HIGH);
    vTaskDelay(pdMS_TO_TICKS(5000));
  }
  digitalWrite(IN1, LOW);
  digitalWrite(IN2, LOW);
  digitalWrite(IN3, LOW);
  digitalWrite(IN4, LOW);
  BLECmd.notify("IDLE");
  digitalWrite(DRV_EEP, LOW);
  Serial.println("[RX] Completed manual command, robot idle");
}

void bleReceiverTask(void *param){
  Serial.println("[BLE] BLE Receiver Task started");
  BLECmd.begin("ESP32_Receiver");
  BLECmd.onCommand(handleCode);
  BLECmd.onVector(handleJoystickVector);
  g_bleReady = true;
  while (true) {
    BLECmd.poll();
    vTaskDelay(pdMS_TO_TICKS(5)); // Yield to other tasks
  }
}

void voltageMonitorTask(void *param){
  Serial.println("[ADC] Voltage monitor task started");
  while (true) {
    if (!g_bleReady) {
      vTaskDelay(pdMS_TO_TICKS(100));
      continue;
    }

    int raw = analogRead(SENSOR_PIN);
    float voltage = raw * (ADC_REF_VOLTAGE / static_cast<float>(ADC_FULL_SCALE));

    Serial.printf("[ADC] Raw: %d | Voltage: %.4f V\n", raw, voltage);

    char msg[32];
    snprintf(msg, sizeof(msg), "ADC:%d Voltage:%.4fV", raw, voltage);
    BLECmd.notify(msg);

    vTaskDelay(pdMS_TO_TICKS(2000));
  }
}

void setup()
{
  Serial.begin(115200);
  delay(1000);
  Serial.println("Starting up");
  // obstacle_init(TRIG_PIN, ECHO_PIN);

  analogReadResolution(12);
  analogSetAttenuation(ADC_11db);
  pinMode(SENSOR_PIN, INPUT);

  pinMode(DRV_EEP, OUTPUT);
  pinMode(IN1, OUTPUT);
  pinMode(IN2, OUTPUT);
  pinMode(IN3, OUTPUT);
  pinMode(IN4, OUTPUT);

  // make sure we don't get killed for our long running tasks
  esp_task_wdt_init(10, false);

  // start up the I2S input (from either an I2S microphone or Analogue microphone via the ADC)
  I2SSampler *i2s_sampler = new I2SMicSampler(i2s_mic_pins, false);
  // the command processor
  CommandProcessor *command_processor = new CommandProcessor();

  // create our application
  CommandDetector *commandDetector = new CommandDetector(i2s_sampler, command_processor);

  // set up the i2s sample writer task
  TaskHandle_t applicationTaskHandle;
  xTaskCreatePinnedToCore(applicationTask, "Command Detect", 8192, commandDetector, 1, &applicationTaskHandle, 0);

  // start sampling from i2s device - use I2S_NUM_0 as that's the one that supports the internal ADC
  i2s_sampler->start(I2S_NUM_0, i2sMemsConfigBothChannels, applicationTaskHandle);

  xTaskCreatePinnedToCore(
    bleReceiverTask, "BLE Receiver", 4096, NULL, 1, NULL, 1
  );

  xTaskCreatePinnedToCore(
    voltageMonitorTask, "Voltage Monitor", 3072, NULL, 1, NULL, 1
  );
}

void loop()
{
  if (g_controllerMode)
  {
    uint32_t now = millis();
    if (now - g_lastVectorMs > CONTROLLER_TIMEOUT_MS)
    {
      stopControllerMotion();
      g_lastVectorMs = now;
    }
    vTaskDelay(pdMS_TO_TICKS(50));
  }
  else
  {
    vTaskDelay(pdMS_TO_TICKS(1000));
  }
}

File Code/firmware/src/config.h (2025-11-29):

// are you using an I2S microphone - comment this out if you want to use an analog mic and ADC input
#define USE_I2S_MIC_INPUT

// I2S Microphone Settings
// Which channel is the I2S microphone on? I2S_CHANNEL_FMT_ONLY_LEFT or I2S_CHANNEL_FMT_ONLY_RIGHT
#define I2S_MIC_CHANNEL I2S_CHANNEL_FMT_ONLY_LEFT
// #define I2S_MIC_CHANNEL I2S_CHANNEL_FMT_ONLY_RIGHT
#define I2S_MIC_SERIAL_CLOCK GPIO_NUM_20
#define I2S_MIC_LEFT_RIGHT_CLOCK GPIO_NUM_19
#define I2S_MIC_SERIAL_DATA GPIO_NUM_18

// Analog Microphone Settings - ADC1_CHANNEL_7 is GPIO35
// #define ADC_MIC_CHANNEL ADC1_CHANNEL_7

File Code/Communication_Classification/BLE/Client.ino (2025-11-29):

#include "BLEDevice.h"

// --- UUIDs ---
static BLEUUID serviceUUID("4fafc201-1fb5-459e-8fcc-c5c9c331914b");
static BLEUUID charUUID("beb5483e-36e1-4688-b7f5-ea07361b26a8");

// --- Connection State ---
static boolean doConnect = false;
static boolean connected = false;
static BLERemoteCharacteristic* pRemoteCharacteristic;
static BLEAdvertisedDevice* myDevice;
static BLEClient* pClient;

// --- Data ---
const int PAYLOAD_SIZE = 500;
uint8_t payload[PAYLOAD_SIZE];
unsigned long lastRssiCheckTime = 0;

class MyClientCallback : public BLEClientCallbacks {
  void onConnect(BLEClient* pclient) {}
  void onDisconnect(BLEClient* pclient) {
    connected = false;
    Serial.println("onDisconnect");
  }
};

bool connectToServer() {
  Serial.print("Forming a connection to ");
  Serial.println(myDevice->getAddress().toString().c_str());
  pClient = BLEDevice::createClient();
  Serial.println(" Created client");
  pClient->setClientCallbacks(new MyClientCallback());
  pClient->connect(myDevice);
  Serial.println(" Connected to server");
  BLERemoteService* pRemoteService = pClient->getService(serviceUUID);
  if (pRemoteService == nullptr) {
    Serial.print("Failed to find our service UUID: ");
    Serial.println(serviceUUID.toString().c_str());
    pClient->disconnect();
    return false;
  }
  Serial.println(" Found our service");
  pRemoteCharacteristic = pRemoteService->getCharacteristic(charUUID);
  if (pRemoteCharacteristic == nullptr) {
    Serial.print("Failed to find our characteristic UUID: ");
    Serial.println(charUUID.toString().c_str());
    pClient->disconnect();
    return false;
  }
  Serial.println(" Found our characteristic");
  connected = true;
  return true;
}

class MyAdvertisedDeviceCallbacks: public BLEAdvertisedDeviceCallbacks {
  void onResult(BLEAdvertisedDevice advertisedDevice) {
    if (advertisedDevice.haveServiceUUID() && advertisedDevice.isAdvertisingService(serviceUUID)) {
      BLEDevice::getScan()->stop();
      myDevice = new BLEAdvertisedDevice(advertisedDevice);
      doConnect = true;
    }
  }
};

void setup() {
  Serial.begin(115200);
  for (int i = 0; i < PAYLOAD_SIZE; i++) payload[i] = i % 256;

  BLEDevice::init("");
  BLEScan* pScan = BLEDevice::getScan();
  pScan->setAdvertisedDeviceCallbacks(new MyAdvertisedDeviceCallbacks());
  pScan->setActiveScan(true);
  pScan->start(5, false);
}

void loop() {
  if (doConnect) {
    if (connectToServer()) {
      Serial.println("We are now connected to the BLE Server.");
    } else {
      Serial.println("Failed to connect to the server.");
    }
    doConnect = false;
  }

  if (connected) {
    pRemoteCharacteristic->writeValue(payload, sizeof(payload));
    if (millis() - lastRssiCheckTime > 1000) {
      lastRssiCheckTime = millis();
      int rssi = pClient->getRssi();
      Serial.print("Current RSSI: ");
      Serial.print(rssi);
      Serial.println(" dBm");
    }
  } else {
    BLEDevice::getScan()->start(5, false);
  }
  delay(10);
}
